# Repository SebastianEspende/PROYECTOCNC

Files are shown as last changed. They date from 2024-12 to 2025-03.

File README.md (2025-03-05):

# TALADRO CNC
### Introduccion

Este proyecto fue pensado y realizado con el fin de diseñar y construir un enrutador CNC de bajo costo, su 
principal función es agujerear placas PCB de producción caseras por estudiantes. Con este dispositivo se 
busca facilitar el proceso de la creación de proyectos que requieran placas electrónicas, permitiendo al 
usuario una mayor precisión y eficiencia en la perforación de placas, en comparación con los métodos 
manuales. Este proyecto también tiene como objetivo fomentar el aprendizaje practico de tecnologías CNC, 
de la electrónica y programación, con el fin de que sea una herramienta útil para los proyectos de electrónica 
y robótica.

#### Repositorio
- En el mismo se encuentran todos los recursos utilizados, como la parte electronica: donde se incluyen los diagramas y circuitos; los diseños 3D de las piezas utilizadas; y el codigo de programacion.
- No se incluyen las librerias, estas estaran al final de este archivo, algunas solo el nombre y otras en enlace a la pagina de donde provienen.

## Software

Se utiliza GRBL 1.1h, se incluye su link en el apartado de librerias

El codigo del ESP32 esta incluido por completo en este repositorio

## Para el futuro
A aquellos que les toque continuar nuestro proyecto, nos gustaria saberlo, les dejamos nuestros mails para que puedan contarnos, o si tienen alguna pregunta:
- espendesebastian@gmail.com
- josemcoronado671@gmail.com

### Palabras de precaución
los pines no son aleatorios, es importante que si quieren cambiarlo tengan en cuenta los grupos o puertos de los pines de un Arduino, si entran al cpu_map de GRBL se daran cuenta de lineas como esta para los 
pines que tienen algo en común como step de cada motor, dir de cada motor, limit switches, etc; 

```javascript
#define STEP_DDR        DDRD
#define STEP_PORT       PORTD
```
DDRD y PORTD no son solo nombres, se refieren al grupo de pines utiliado por los STEP en este caso, otro ejemplo
```javascript
#define DIRECTION_DDR     DDRD
#define DIRECTION_PORT    PORTD
```
Ambos utilizan el grupo D, que son del pin 0 al 7.
Grupo B utiliza pin 8 al 13.
es por eso que la declaracion de pines pareciera incorrecta, ejemplo 
#define X_LIMIT_BIT      1
Que utiliza el pin 9 pero se declara como 1, esto se debe a que utiliza el grupo B.

Para que la comunicacion entre el ESP32 y el Arduino funcione, tienen que tener el mismo GND, o al menos, conectarlos

### Librerias

- https://lcdmenu.forntoh.dev/overview/getting-started.html#installation
- https://github.com/gnea/grbl/releases/tag/v1.1h.20190825

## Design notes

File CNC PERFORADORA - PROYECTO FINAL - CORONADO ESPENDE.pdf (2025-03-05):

# PROYECTO FINAL

CICLO LECTIVO 2025

+

## CNC PERFORADORA DE PCB

# CORONADO JOSÉ | ESPENDE SEBASTIAN 7° ELECTRONICA E.S.E.T.P. N°703

## ÍNDICE

## CONTENIDO

## INTRODUCCIÓN

Este proyecto fue pensado y realizado con el fin de diseñar y construir un enrutador CNC de bajo costo, su principal función es agujerear placas PCB de producción caseras por estudiantes. Con este dispositivo se busca facilitar el proceso de la creación de proyectos que requieran placas electrónicas, permitiendo al usuario una mayor precisión y eficiencia en la perforación de placas, en comparación con los métodos manuales. Este proyecto también tiene como objetivo fomentar el aprendizaje practico de tecnologías CNC, de la electrónica y programación, con el fin de que sea una herramienta útil para los proyectos de electrónica y robótica.

Las placas PCB (Printed Circuit Board o circuito impreso) en nuestro ámbito estudiantil son muy importantes, ya que podemos definirlas como la culminación de un proyecto que hayamos realizado primeramente en una placa de pruebas o bien un diseño de un circuito que queramos armar. Las placas están conformadas por una o más capas, en el caso de los estudiantes acostumbramos a usar el tipo de placa que está conformado por un material aislante que puede ser una resina y una capa fina de cobre.

Cuando se realizan placas electrónicas de producción “caseras” se pueden emplear distintos métodos para la realización de pistas, que serán la conexión entre los componentes electrónicos, una de ellas es el uso de marcadores indelebles para realizar el trazo y recorrido de las pistas. Otro método es el uso de tóner, el cual primeramente debemos diseñar el circuito en algún programa como lo puede ser PCB Wizard o KiCad.

PCB WIZARD:

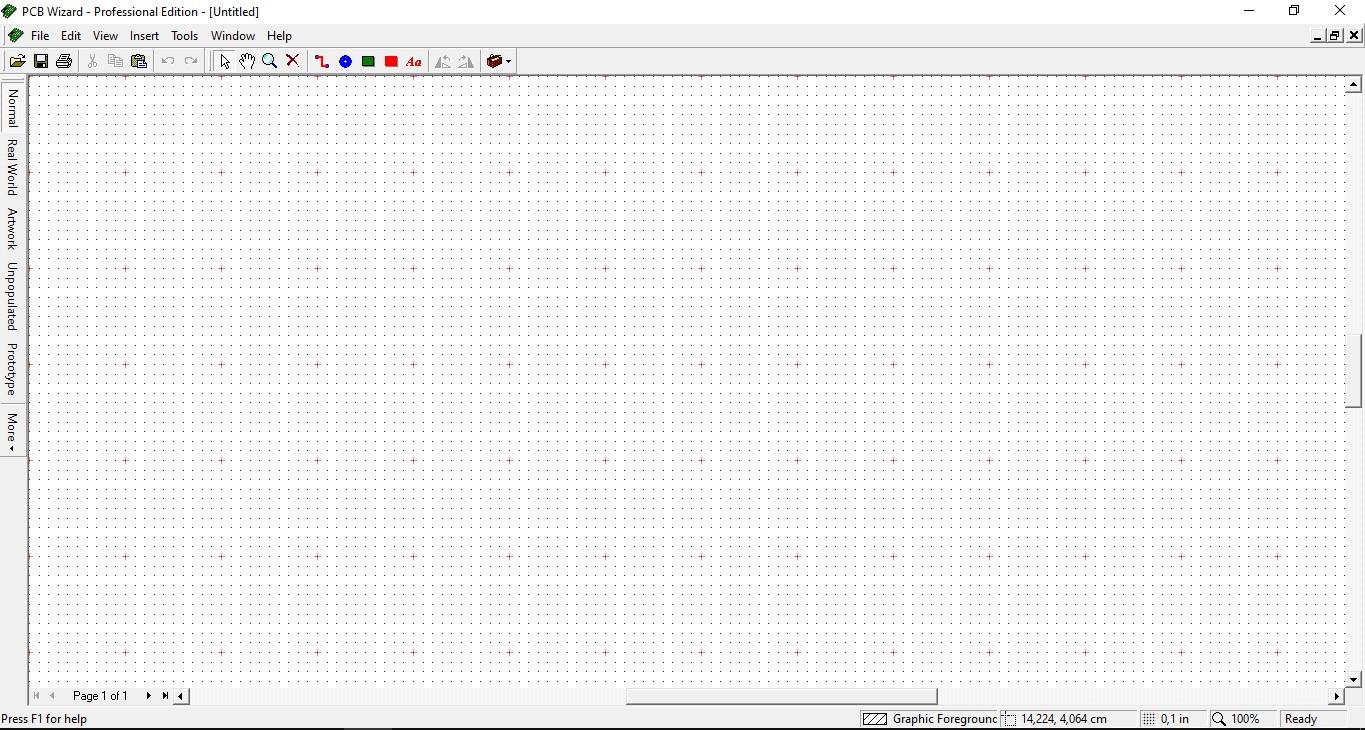
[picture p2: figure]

PCB Wizard es un software de diseño de circuitos impresos que destaca por su facilidad de uso y sus capacidades versátiles. Este programa tiene una interfaz sencilla y ofrece herramientas para diseñar un PCB estándar. Incluye funcionalidades como el dibujo esquemático, la conversión a circuito impreso y el posicionamiento de componentes electrónicos. Además, cuenta con una opción de autoruteado que simplifica el proceso de diseño.

Entre las características adicionales, PCB Wizard permite generar reportes de materiales, lo cual es crucial para llevar un control detallado de los componentes necesarios para el ensamblaje del circuito. También ofrece la posibilidad de realizar simulaciones para verificar el funcionamiento del diseño, con el programa Livewire, antes de la fabricación. La integración con otras herramientas de software y la capacidad de exportar archivos en distintos formatos hacen de PCB Wizard una opción atractiva tanto para estudiantes como para profesionales que buscan un software de diseño de PCBs eficiente y accesible.

KiCad:

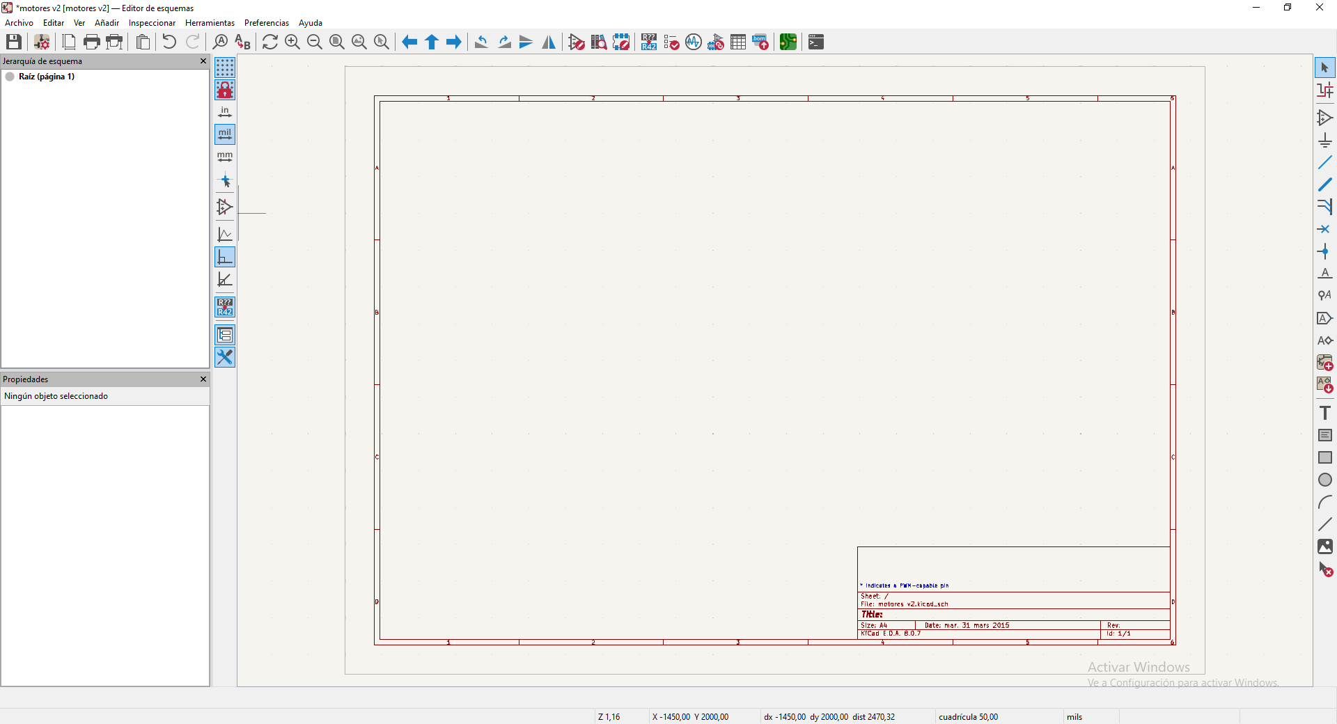
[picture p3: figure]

Este programa tiene una interfaz sencilla y ofrece herramientas avanzadas para el diseño de PCBs. Incluye dibujo esquemático, conversión a circuito impreso, posicionamiento de componentes, autoruteado y gestión de bibliotecas. Además, permite la visualización 3D del diseño y la generación de archivos Gerber para la fabricación de las placas. La integración con otras herramientas de software y la capacidad de exportar archivos en distintos formatos hacen de KiCad una opción atractiva tanto para estudiantes como para profesionales que buscan un software de diseño de PCBs eficiente y accesible.

Luego del proceso de fabricación de PCBs se requiere perforar la placa para poder realizar el montaje de los componentes electrónicos, tales como: componentes pasivos o componentes activos.

Para la realización de las perforaciones se puede usar taladros de mano o de banco, lo cual puede aumentar el error humano por las siguientes razones:

1. Precisión:
- Al perforar manualmente puede haber error en la alineación de la placa, debido a que no se utilizan guías o plantillas para mantener la estabilización de la placa. Esto puede representar un error de un 5% a 10% en la posición de los orificios.
2. Daños en la PCB:
- El error humano puede provocar daños en las pistas de cobre o en las islas de la placa, y este aumenta si se usa un taladro de mano, ya que se perfora en un ángulo incorrecto o se aplica demasiada fuerza. Esto puede representarse con un 3% a 5% de error en los agujeros.
3. Profundidad de perforación:
- La profundidad de los agujeros puede llegar a ser diferentes entre cada perforación, esto afecta al momento de colocar los componentes, ya que en algunos casos puede que estos no logren ingresar fácilmente por el orificio. Esto representa un 2% a 4% de error humano.
4. Tiempo y eficiencia:
- El tiempo requerido para perforar manualmente una PCB es mayor al que con una CNC, y el cansancio puede aumentar la probabilidad de errores.

El proyecto de la CNC busca reducir este margen de error humano, ya que el mismo posee un soporte/guía para mantener la placa estable, las perforaciones siempre se realizan a un ángulo recto de 90°, la fuerza aplicada es siempre la misma, la profundidad de igual manera siempre es la misma y el tiempo que emplea es mucho menor.

## MARCO TEORICO

Una CNC (Control Numérico Computarizado) es un dispositivo que se controla por computadora con el fin de cortar, tallar, grabar o perforar materiales con alta precisión. En el caso de este proyecto, el enrutador CNC está diseñado específicamente para la realización de perforaciones en placas PCB.

Una máquina CNC puede tener diferentes diseños y estar hecha de diversos materiales, pero hay componentes que son indispensables en todas ellas. Estos incluyen motores paso a paso, guías lineales y herramientas como perforadores o cortadores, dependiendo del uso que se les quiera dar.

Esta CNC está compuesta
por | varios | elementos
esenciales que trabajan en conjunto para garantizar su funcionamiento. Entre ellos, se encuentran los motores
paso a paso, que permiten
un movimiento preciso en
cada eje, las guías lineales,
que | facilitan | el
desplazamiento | suave | y
estable de la herramienta, y
el | motor | perforador,
encargado de realizar los
orificios en la placa PCB.

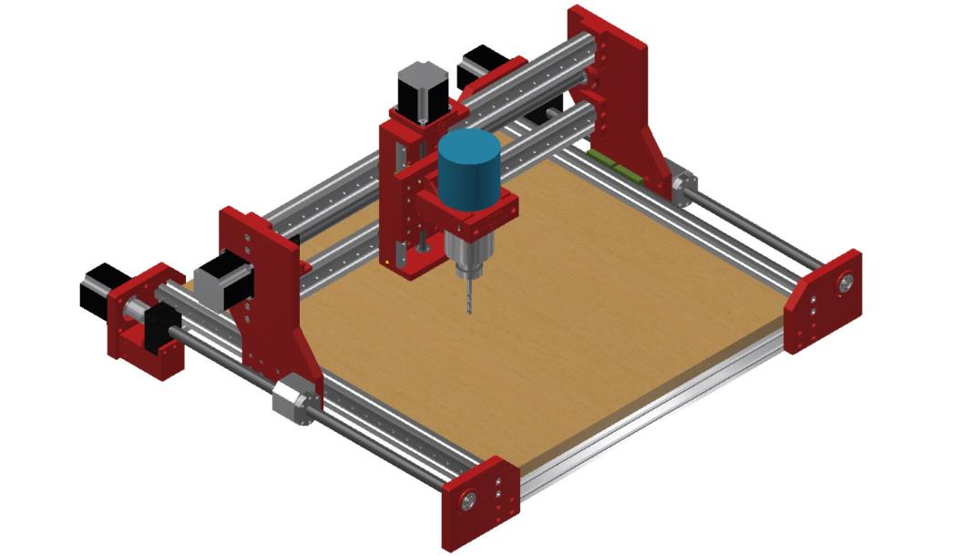
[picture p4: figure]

Además, la estructura y la placa de trabajo proporcionan la base necesaria para soportar todos estos componentes y asegurar la rigidez del sistema.

Los materiales utilizados en su fabricación pueden variar según el tipo de máquina y su propósito. En proyectos caseros o educativos, es común encontrar estructuras de aluminio, plásticos o madera, mientras que en la industria suelen emplearse materiales más robustos como el acero para garantizar mayor resistencia y durabilidad.

Cada uno de estos materiales y componentes cumple un rol fundamental en el rendimiento de la CNC. Una estructura firme reduce vibraciones y mejora la precisión, mientras que unas guías bien alineadas permiten movimientos más suaves. De esta manera, todos los elementos trabajan en conjunto para lograr perforaciones exactas y eficientes en las placas PCB.

## ESTRUCTURA

La estructura de una máquina CNC es una parte clave, ya que brinda soporte y estabilidad a todo el sistema. Está formada por un marco o chasis, guías lineales, husillos o tuercas, y una plataforma de trabajo. Todos estos elementos trabajan en conjunto para asegurar que la herramienta de perforación se desplace con precisión sobre la placa PCB.

## MOTORES PASO A PASO:

Los motores paso a paso son un componente esencial en una máquina CNC, ya que permiten un control preciso del movimiento en los ejes X, Y e Z. A diferencia de otros motores, los motores paso a paso se desplazan en incrementos exactos (pasos), lo que facilita un posicionamiento preciso de la herramienta de perforación sobre la placa PCB.

Estos motores funcionan mediante pulsos eléctricos que activan sus bobinas en una secuencia específica, generando movimientos controlados sin necesidad de sensores de posición adicionales. Existen dos tipos principales:

- Motores de pasos completos (full-step): Se mueven en pasos fijos, adecuados para aplicaciones donde la precisión no es extrema.
- Motores de micro pasos (microstepping): Dividen cada paso en fracciones más pequeñas, proporcionando mayor suavidad y precisión en los movimientos.

La elección del motor adecuado es muy importante en una CNC para PCB. Un motor con bajo torque podría perder pasos, causando errores en la perforación, mientras que un motor muy grande puede ser innecesario y consumir más energía. Generalmente, se utilizan motores NEMA 17 o NEMA 23, que ofrecen un buen equilibrio entre tamaño, potencia y precisión.

El uso de motores paso a paso en una CNC educativa permite a los estudiantes comprender principios de control de movimiento y automatización, habilidades fundamentales en la ingeniería y la manufactura.

## GUÍAS Y VARILLAS ENROSCADAS:

Las guías son un componente esencial en la estructura de la CNC, ya que permiten tanto la movilidad como la estabilidad del sistema. Las guías lineales, en particular, facilitan un movimiento lineal suave y preciso a lo largo de los ejes X, Y e Z. Estas guías están diseñadas para minimizar la fricción y el juego mecánico, lo que garantiza que los movimientos sean consistentes y exactos, incluso durante operaciones repetitivas. Esto es especialmente importante en aplicaciones como la perforación de placas PCB, donde la precisión en el posicionamiento es crítica para asegurar que los agujeros estén correctamente alineados y dimensionados.

Las varillas roscadas desempeñan un papel crucial en la conversión del movimiento rotativo del eje del motor en movimiento lineal. Cuando el motor paso a paso gira, la rotación se transmite a la varilla roscada, que a su vez mueve una tuerca o un acoplador a lo largo de su longitud. Este mecanismo permite un desplazamiento lineal preciso y controlado, esencial para el posicionamiento exacto de la herramienta de corte en los ejes X, Y y Z de la CNC. La precisión de este sistema depende en gran medida del paso de la rosca de la varilla, que determina la distancia que se desplaza la tuerca por cada vuelta completa del motor. Este diseño es fundamental para garantizar movimientos suaves y repetibles, lo que es especialmente importante en
aplicaciones | como | la | perforación | de | placas | PCB, | donde | la | exactitud | es | crítica.

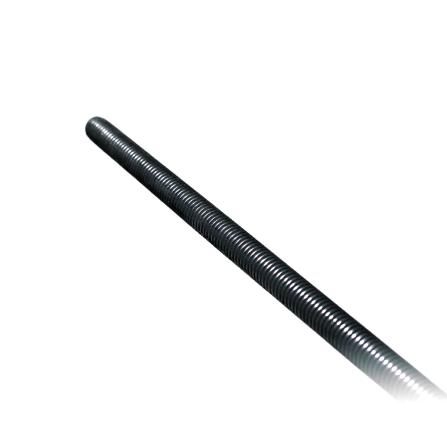
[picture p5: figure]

## SISTEMA DE CONTROL

El sistema de control es el "cerebro" de la máquina CNC, ya que se encarga de interpretar las órdenes y convertirlas en movimientos precisos en los ejes de la máquina. En este caso, el sistema está basado en una placa programable Arduino junto con el firmware de código abierto GRBL, una combinación que permite analizar y ejecutar instrucciones escritas en código G.

El código G es el lenguaje estándar utilizado en máquinas CNC para indicar qué movimientos debe realizar la herramienta de trabajo. Cuando se carga un archivo con código G en la CNC, el Arduino con GRBL lo interpreta y envía las señales necesarias a los controladores de los motores paso a paso, quienes a su vez mueven la herramienta en los ejes X, Y e Z con precisión.

Uno de los principales beneficios de este sistema es su bajo costo en comparación con controladores CNC comerciales, que pueden ser bastante costosos. Además, al ser un sistema de código abierto, GRBL es accesible y ampliamente utilizado, lo que significa que cuenta con una gran comunidad de usuarios y desarrolladores que ofrecen soporte, mejoras y soluciones a posibles problemas.

Otra ventaja es su facilidad de uso y configuración. No se necesita un software complejo para programarlo, y se puede controlar desde una computadora mediante programas como Universal Gcode Sender o Candle, que permiten cargar y enviar los archivos de código G de manera sencilla.

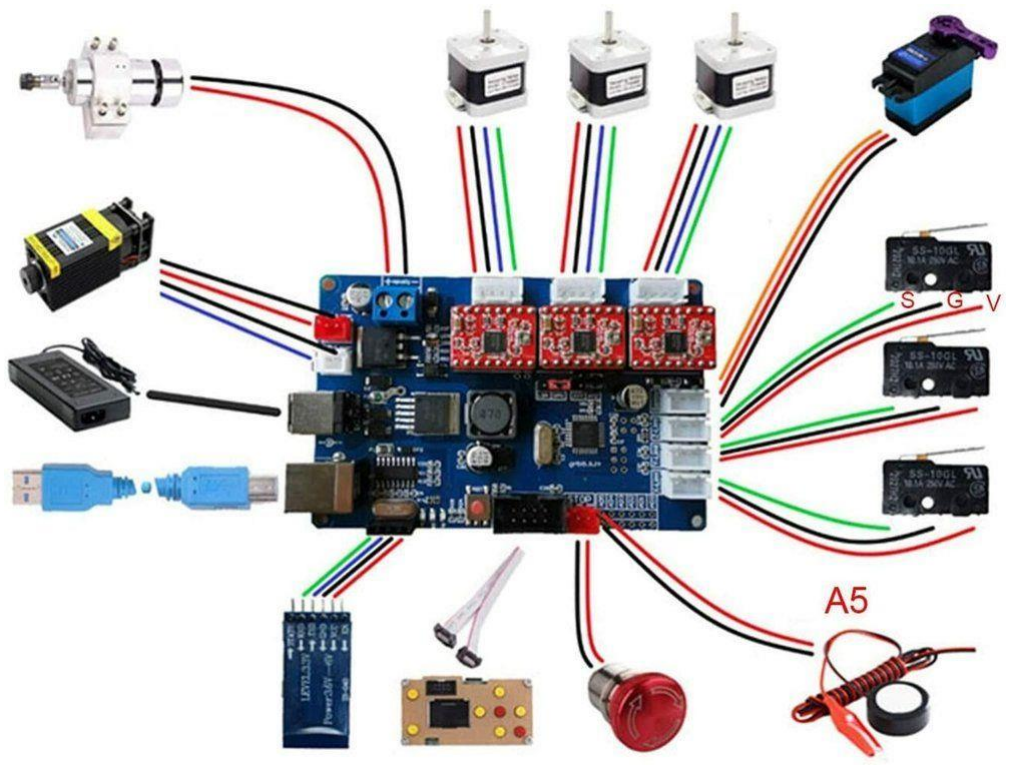
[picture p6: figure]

En esta imagen podemos apreciar los materiales básicos para una CNC, en donde tenemos los 3 motores paso a paso, 3 fines de carreras para limitar la posición de los ejes, un elemento perforador o cortador, una fuente de poder, un lector de memorias SD, una pantalla con pulsadores, los drivers de motores, etc.…

## DISEÑO Y DESARROLLO

## ETAPAS DEL DISEÑO CNC:

El primer paso en el desarrollo de la CNC fue la creación de un prototipo digital utilizando SolidWorks, un software especializado en diseño 3D. Este programa permitió modelar cada uno de los componentes de la máquina, como la estructura, los motores, las guías lineales y el sistema de perforación, asegurando que todas las piezas encajaran correctamente antes de la fabricación.

Gracias a SolidWorks, fue posible visualizar el diseño en un entorno virtual, realizar simulaciones de movimiento y detectar posibles fallos estructurales o de ensamblaje. Además, nos permitió optimizar el uso de materiales y prever los ajustes necesarios para garantizar un montaje preciso y funcional.

Una vez que el diseño digital estuvo finalizado y validado, se procedió a la fabricación del prototipo físico, utilizando los materiales adecuados y ensamblando cada componente según lo planificado en el modelo 3D. Este proceso facilitó la transición del diseño teórico a una máquina real, minimizando errores y asegurando un mejor resultado en la construcción de la CNC.

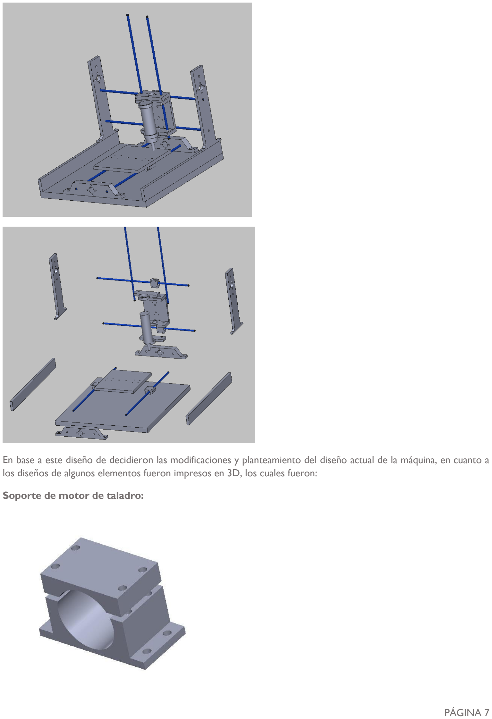
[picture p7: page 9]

En base a este diseño de decidieron las modificaciones y planteamiento del diseño actual de la máquina, en cuanto a los diseños de algunos elementos fueron impresos en 3D, los cuales fueron:

Soporte de motor de taladro:

Soporte eje Y:

El mismo consta con dos orificios para la colocación de rodamientos lineales que permitirán un movimiento más suave por los ejes.

Soporte lineales:

Estos soportes son utilizados en conjunto con un rodamiento lineal, se utilizan en los ejes X e Z.

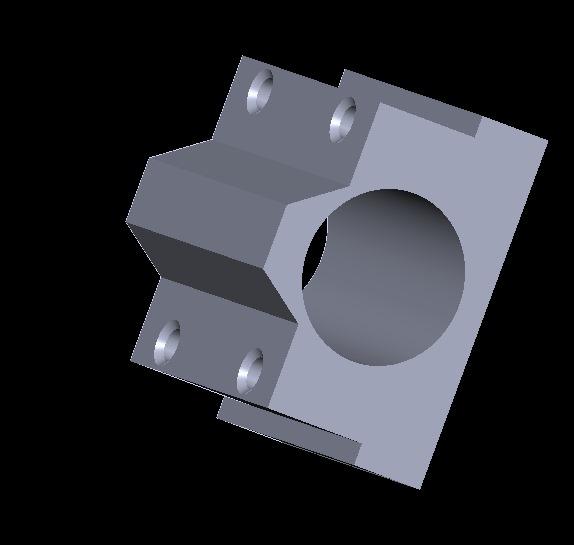
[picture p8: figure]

Soporte para motores Nema17:

Se utiliza para soportar los motores, los orificios chicos son para el acople del motor y los separadores son para acoplar a la base del CNC.

Soporte de tuerca M8:

El soporte en conjunto con una tuerca, se encargan del desplazamiento en los ejes.

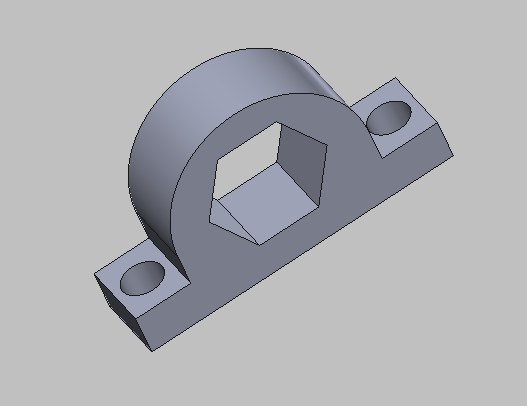
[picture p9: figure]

Soporte del eje X:

Este soporte acoplado a la base soporta dos varillas lineales y el motor en el centro.

Base:

Una tabla de madera con una medida de 400mm x 400mm

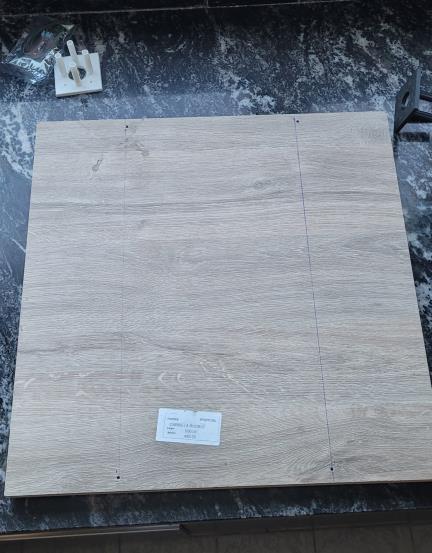
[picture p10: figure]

Se deben realizar cuatro perforaciones en las piezas con medidas precisas, ya que estas deben acoplar los soportes de las guías y varillas del eje X.

Soportes laterales:

Dos maderas de 100mm x 400mm

A cada una de las maderas se le deben realizar tres perforaciones. Dos de ellas con un diámetro de 8 mm que están destinadas a acoplar las varillas guías que conectan las piezas. La perforación central, por su parte, tiene un diámetro de 22 mm. En una de las maderas, se debe instalar un rodamiento con medidas de 8 mm en su diámetro interior y 22 mm en el exterior.

Estas maderas cumplen la función de soportes laterales de la estructura. Junto con las varillas guías, permiten el desplazamiento suave y preciso del taladro a lo largo del eje Z de la CNC, facilitando el movimiento vertical necesario para
realizar | las | perforaciones | en | las | placas | PCB.

## PROCESO DE ARMADO:

En esta etapa además de los materiales previamente mencionados, se necesitan de materiales menores, tales como: tornillos; tuercas; arandelas; varillas roscadas; etc.

Estos se pueden conseguir fácilmente en ferreterías.

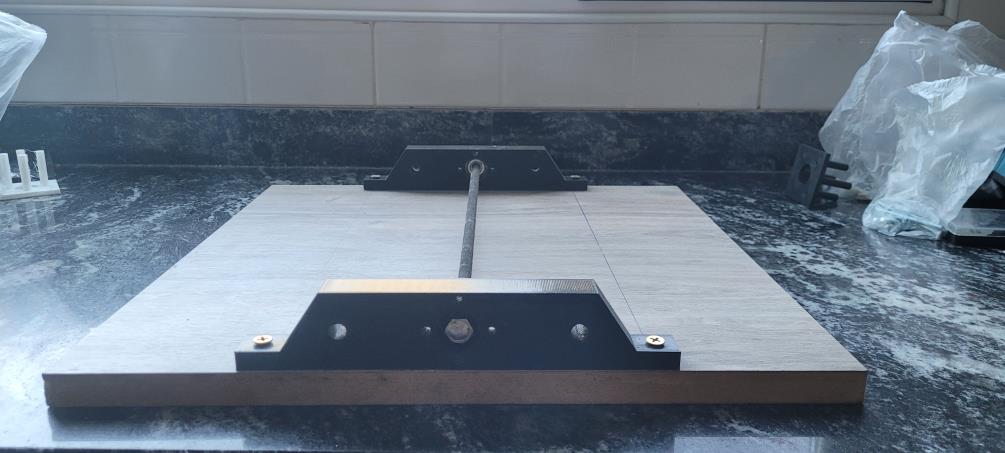
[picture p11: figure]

Se debe acoplar los soportes del eje X a la tabla de 400mm x 400mm, se debe comprobar
que ambas estén en las mismas posiciones para que a futuro no haya problemas de alineación para que los motores no tengan que esforzarse demás por la fricción.

Se debe colocar los soportes lineales a la base y colocar en el centro una tuerca M8 para que se realice el movimiento lineal según el giro del motor. La sujeción de los soportes y la tuerca se puede realizar con tornillos u pegamentos.

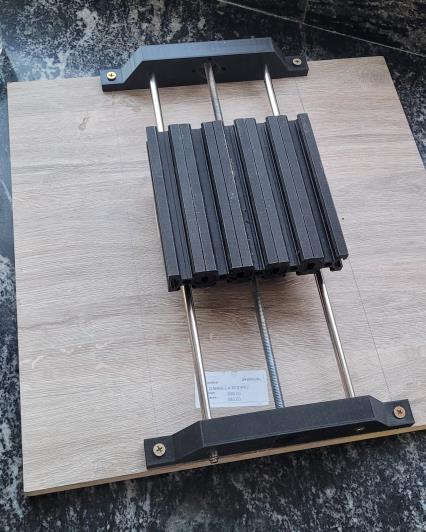
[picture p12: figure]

Una vez armada la base con sus soportes, se deben colocar las varillas y comprobar que la base se desplace según el giro de la varilla.

Terminando esta etapa del proyecto se puede realizar el montaje de los otros ejes, debido a que se necesita saber la posición de la base cuando se encuentra en uno de los extremos.

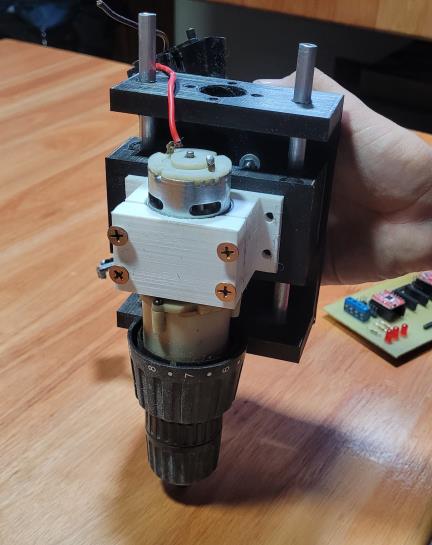
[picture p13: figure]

Previamente se debe realizar el montaje del taladro, el mismo consta de 3 piezas impresas 3D, en donde uno es el soporte del motor, otro es el soporte que realizara el movimiento vertical y por último el soporte que realizara el movimiento horizontal.

Para el taladro se reciclo el motor y el mandril de un taladro de mano.

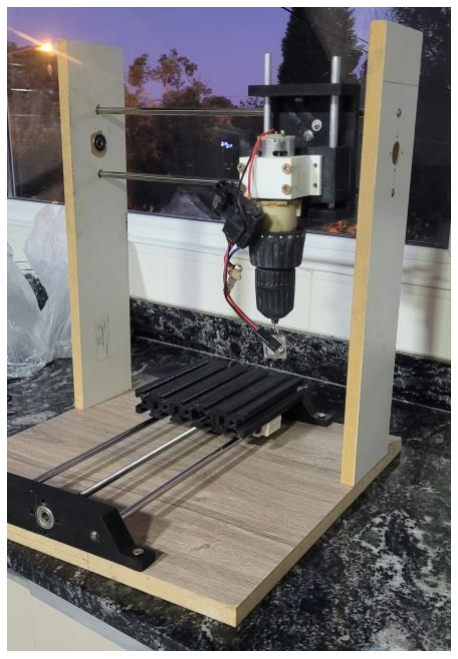
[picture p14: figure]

Teniendo todas las piezas armadas y en posición, se puede realizar el montaje de todas las maderas a la base, hay que comprobar las posiciones antes de
realizar | las | perforaciones.

## PARTE ELECTRONICA:

Para la parte electrónica del proyecto se requieren de varios materiales, que bien fácilmente se pueden comprar o armar por nosotros mismos:

- Shield Arduino:

Este shield de Arduino Uno es una opción buena para este proyecto, pero en el caso de este proyecto se fabricó un prototipo de este shield.

Circuito esquemático:

Este shield cuenta con las conexiones para los motores paso a paso, la salida de 12V para el motor del taladro, los fines de carrera y una conexión RX e TX para conectar el Arduino con el ESP32.

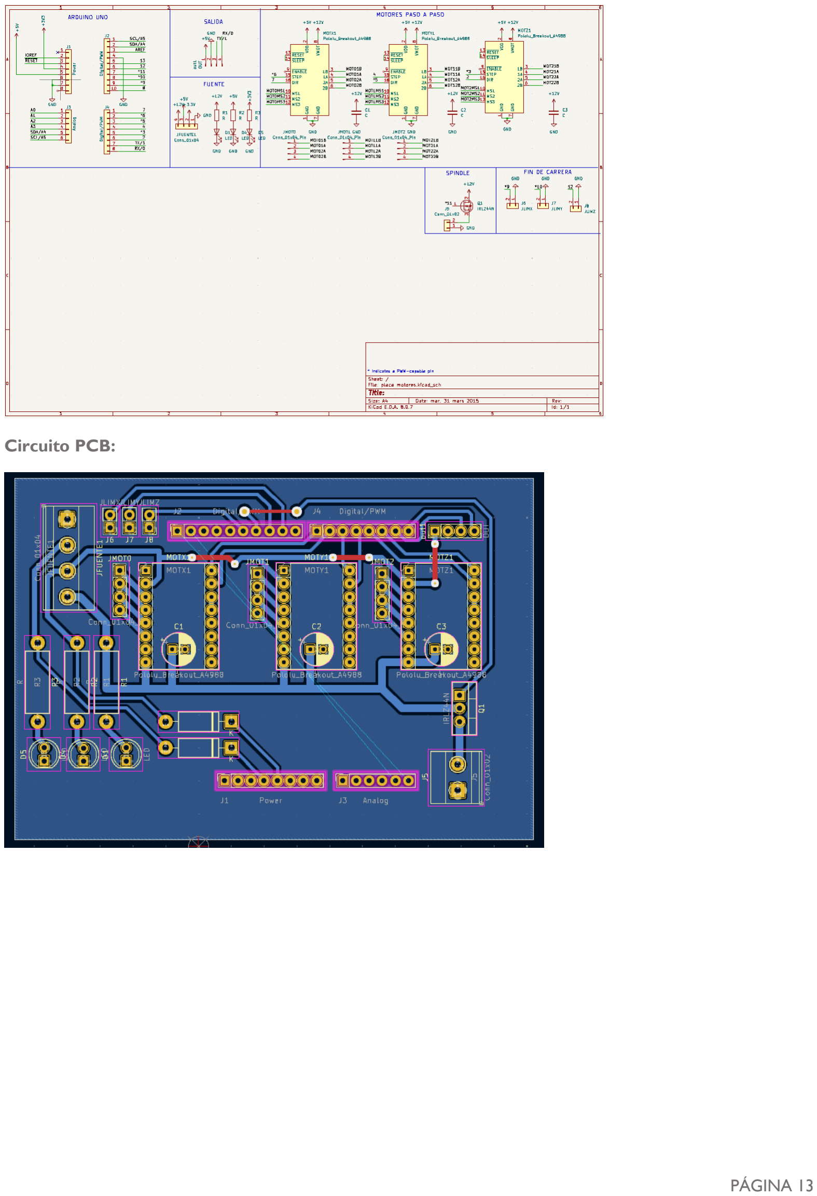
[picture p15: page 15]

Circuito PCB:

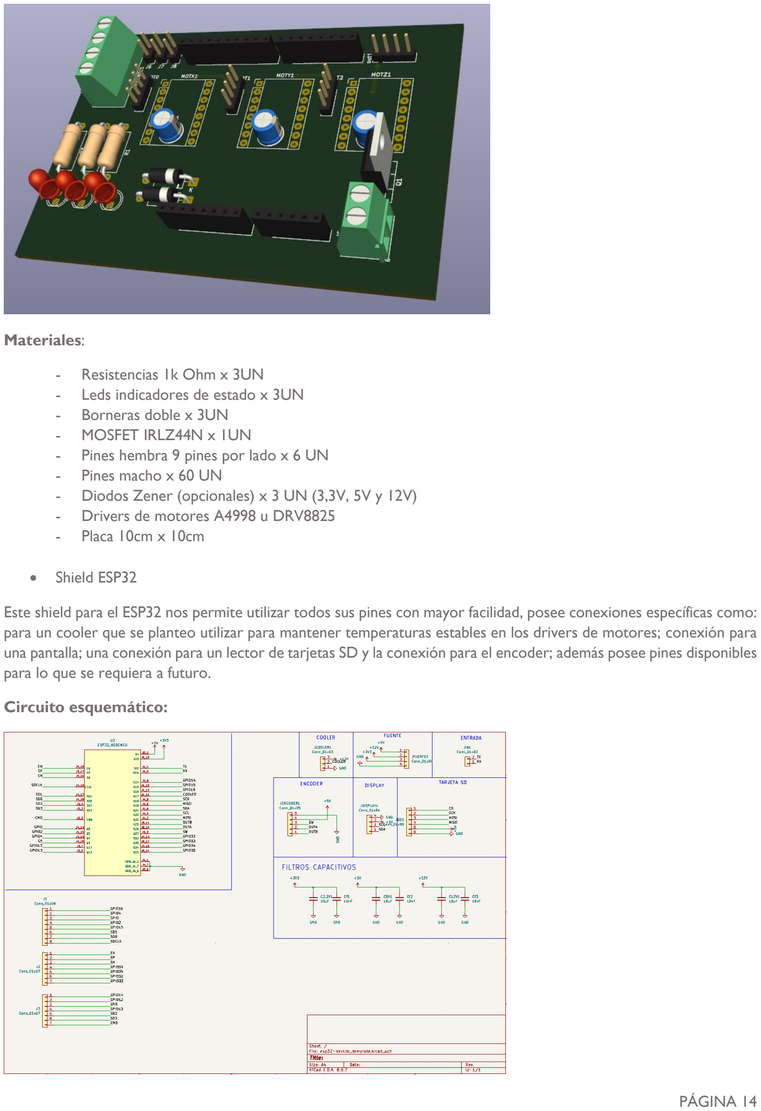
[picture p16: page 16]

Materiales:

- Resistencias 1k Ohm x 3UN
- Leds indicadores de estado x 3UN
- Borneras doble x 3UN
- MOSFET IRLZ44N x 1UN
- Pines hembra 9 pines por lado x 6 UN
- Pines macho x 60 UN
- Diodos Zener (opcionales) x 3 UN (3,3V, 5V y 12V)
- Drivers de motores A4998 u DRV8825
- Placa 10cm x 10cm
- Shield ESP32

Este shield para el ESP32 nos permite utilizar todos sus pines con mayor facilidad, posee conexiones específicas como: para un cooler que se planteo utilizar para mantener temperaturas estables en los drivers de motores; conexión para una pantalla; una conexión para un lector de tarjetas SD y la conexión para el encoder; además posee pines disponibles para lo que se requiera a futuro.

Circuito esquemático:

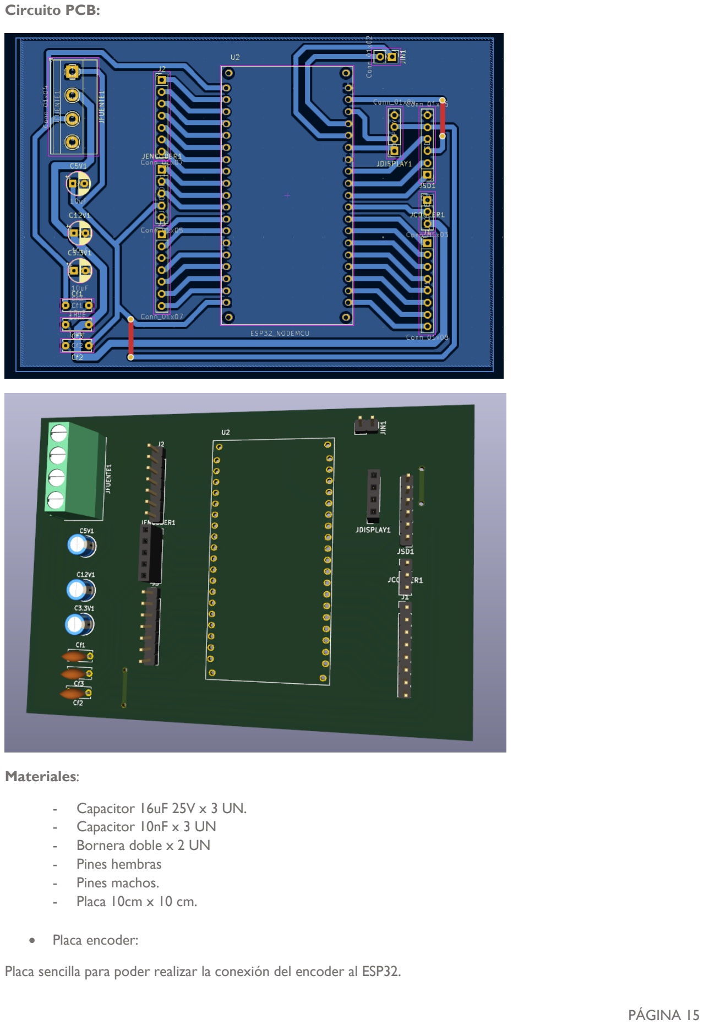
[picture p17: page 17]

Circuito PCB:

Materiales:

- Capacitor 16uF 25V x 3 UN.
- Capacitor 10nF x 3 UN
- Bornera doble x 2 UN
- Pines hembras
- Pines machos.
- Placa 10cm x 10 cm.
- Placa encoder:

Placa sencilla para poder realizar la conexión del encoder al ESP32.

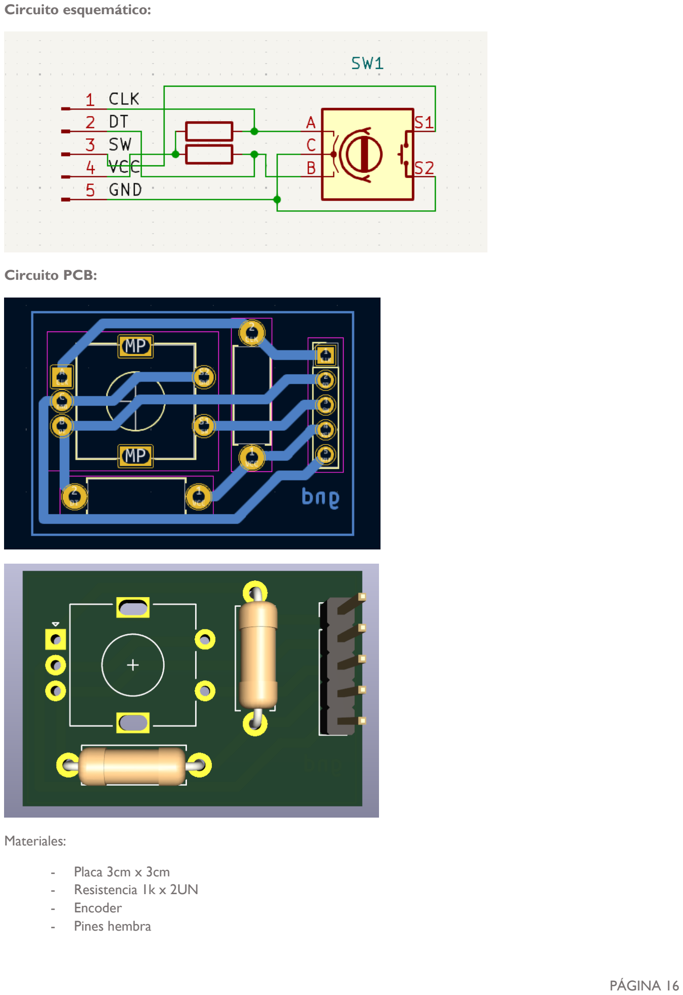
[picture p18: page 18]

Circuito esquemático:

Circuito PCB:

Materiales:

- Placa 3cm x 3cm
- Resistencia 1k x 2UN
- Encoder
- Pines hembra

- Alimentación:

Para la alimentar toda la maquina se puede utilizar una fuente de poder reciclada, en donde necesitaremos realizar unas modificaciones debido a que únicamente necesitaremos 4-5 cables de esta.

## GRBL

GRBL es un firmware de código abierto y alto rendimiento para controlar máquinas CNC (Control Numérico
Computarizado), | como | fresadoras, | grabadoras | láser | y | cortadoras | de | plasma.

GRBL recibe comandos en G-code, un lenguaje de programación estándar utilizado en la industria CNC. El G-code especifica las coordenadas, velocidades y otras instrucciones para el movimiento de la herramienta. GRBL actúa como un intérprete, traduciendo estos comandos en señales eléctricas que controlan los motores de la máquina.

Este está diseñado para controlar motores paso a paso, que son motores eléctricos que giran en incrementos precisos. El firmware genera pulsos eléctricos que controlan el movimiento de los motores, permitiendo un posicionamiento preciso de la herramienta. GRBL optimiza la aceleración y desaceleración de los motores para lograr movimientos suaves y precisos.

## SOFTWARE ESP-32

## COMUNICACION CON GRBL

Los creadores de GRBL, recomiendan varios protocolos de comunicación para interconectar con GRBL, en nuestro
caso | utilizaremos | un | protocolo | de | transmisión | envio-respuesta

El protocolo de transmisión de envío-respuesta se presenta como el método más robusto y sencillo para la transmisión de programas de código G a GRBL. Este protocolo opera mediante el envío secuencial de líneas de código G desde el transmisor a GRBL, seguido de una espera de confirmación, ya sea una respuesta 'ok' o 'error', antes de proceder con el envío de la siguiente línea.

Esta metodología garantiza la integridad de la transmisión al sincronizar la ejecución entre el transmisor y GRBL. La confirmación de recepción permite que el transmisor verifique que cada línea de código G ha sido procesada correctamente por GRBL, independientemente de las posibles demoras en el procesamiento o la ejecución de las instrucciones por parte de GRBL.

La implementación de este protocolo asegura que no se pierdan instrucciones y que la secuencia de ejecución se mantenga precisa, lo que resulta crucial para la operación correcta de sistemas de control numérico.

Comenzamos | definiendo | dos | protocolos | UART | en | el | ESP32

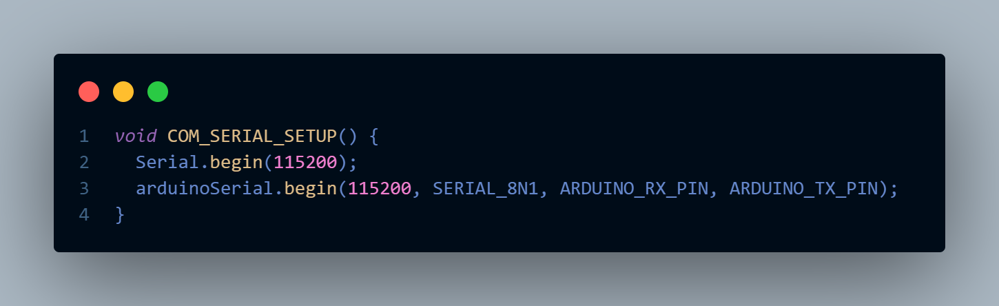
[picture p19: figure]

Serial se utilizará para monitorear el comportamiento del ESP32 y para debuggear cualquier error.

Arduino Serial se utilizará para comunicarse del GRBL

Esta distinción se debe a que, si queremos utilizar la misma interfaz UART toda información enviada del esp32 será recibida por el Arduino, incluido cualquier mensaje de debug, lo que puede traer conflicto con GRBL.

Luego de esto, continuamente revisaremos si hay algún mensaje que ha sido enviado por GRBL:

En un archivo de código G, cada línea es uno o varios movimientos de distintos tipos, desde precisos hasta lineales rápidos. Necesitamos enviar línea por la línea del archivo al GRBL, por lo que, necesitamos una función que procesé un archivo seleccionado y envié la información a GRBL

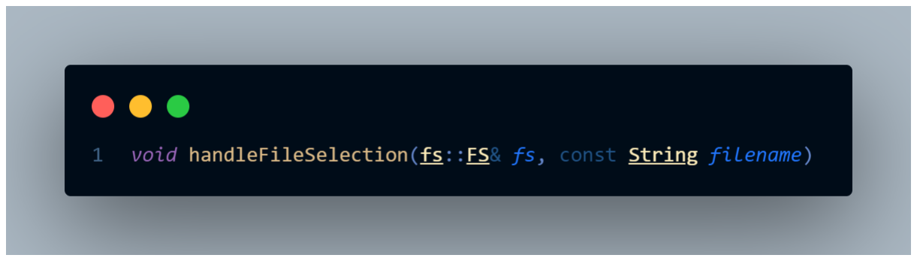
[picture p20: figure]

HandleFileSelection hace exactamente eso, empieza intentando abrir el archivo y devolver un error en caso de que sea necesario:

Una vez que pasemos este proceso, sabemos que el archivo se ha podido abrir correctamente por lo que prosigue
procesar | las | líneas:

GRBL distingue una línea de otra ya sea por una nueva línea “\n” o un “retorno de carruaje” “\r”

Nótese la distinción entre enviar la línea al Serial y al Serial de comunicación con GRBL

Además, no queremos enviar una línea vacía, por lo que debemos asegurarnos de que ese no sea el caso.

Mas adelante se explicará cómo se selecciona el archivo.

## TARJETA SD

Hay tres cosas importantes que se deben hacer con la tarjeta SD, poder listar todos los archivos que contiene, accederlos y leer cada línea.

Para | la | primera | listDir | hace | exactamente | eso.

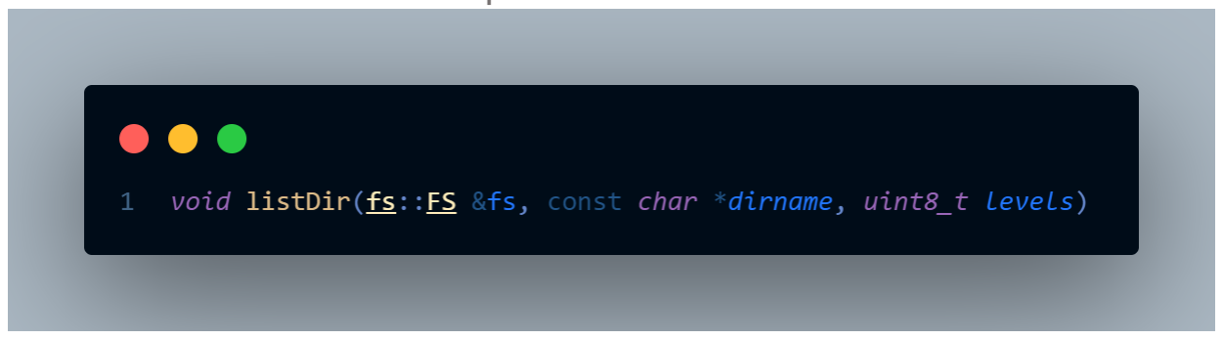
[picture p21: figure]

Su funcionamiento es muy sencillo, simplemente utilizaremos la librería incluida con el ESP para acceder a la ruta y a
cada | uno | de | sus | archivos

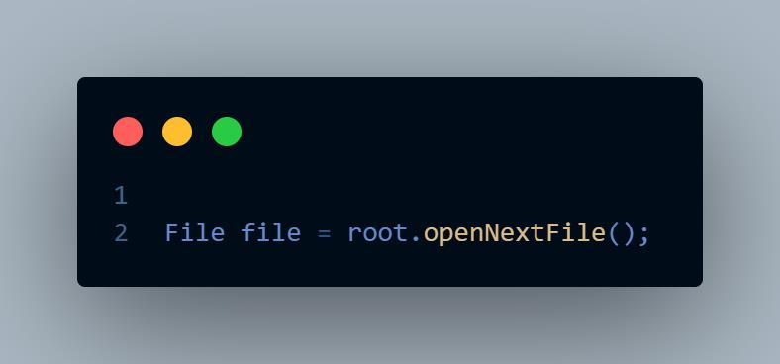
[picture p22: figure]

También | debemos | asegurarnos | de | incluir | cualquier | carpeta | dentro | del | directorio:

Leer cada línea es aún más simple, una vez comenzamos a leer el archivo simplemente nos detendremos en cada “\n”
o | “\r”

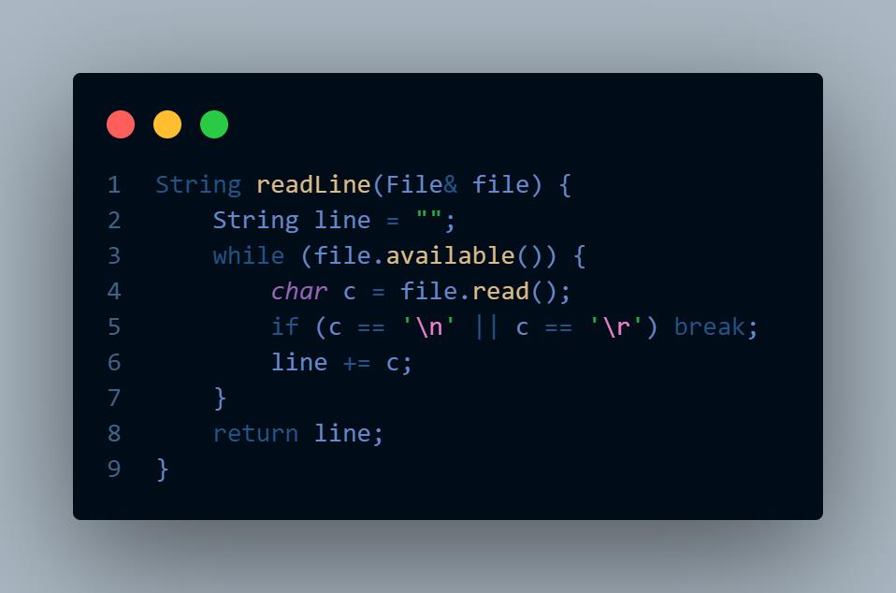
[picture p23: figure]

## WIFI

El WIFI se utilizará para conectarse al servidor y poder recibir archivos a través de la red y no tener que utilizar la
tarjeta | | | | | | | | | | | | SD.
Actualmente | solo | podemos | conectarnos | a | internet, | pero | no | podemos | hacer | nada | con | eso.

Comenzamos poniendo la antena en modo estación, en la que solo podemos enviar y recibir, luego conectándonos a una red a través de wifistart, que enviara los valores por defecto de SSID y contraseña, que en caso de que no sea
modificado | | | estarán | | | | vacíos.
BuildWifiScreen | será | explicado | en | el | apartado | de | LCD.
Debemos hacer dos cosas en este apartado, escanear las redes y conectarnos.

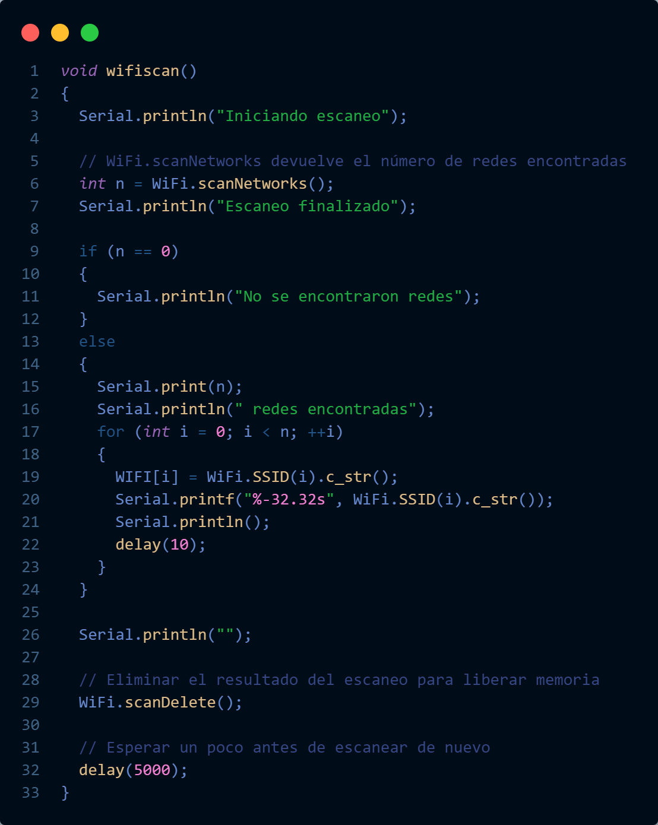
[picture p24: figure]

Wifiscan, hace exactamente lo que dice su nombre, buscamos las redes disponibles y las guardamos en un Array para su uso posterior.

Wifistart nos conectara dado un SSID y una contraseña, y logeara su resultado.

## LCD

El | LCD | es | lo | que | nos | permite | controlar | la | CNC, | por | tanto, | debemos | poder:
- | Seleccionar | un | archivo | ya | sea | desde | la | SD | o | el | Servidor.
- | Conectarnos | a | WIFI
- Obtener información sobre el estado actual de la maquina

Archivos

Con lo explicado antes en el apartado de SD, ya tenemos una manera de enlistar todos los archivos dentro de un directorio, por lo que simplemente deberemos crear un nuevo ítem para cada archivo, con una función como callback para poder hacer algo sobre él.

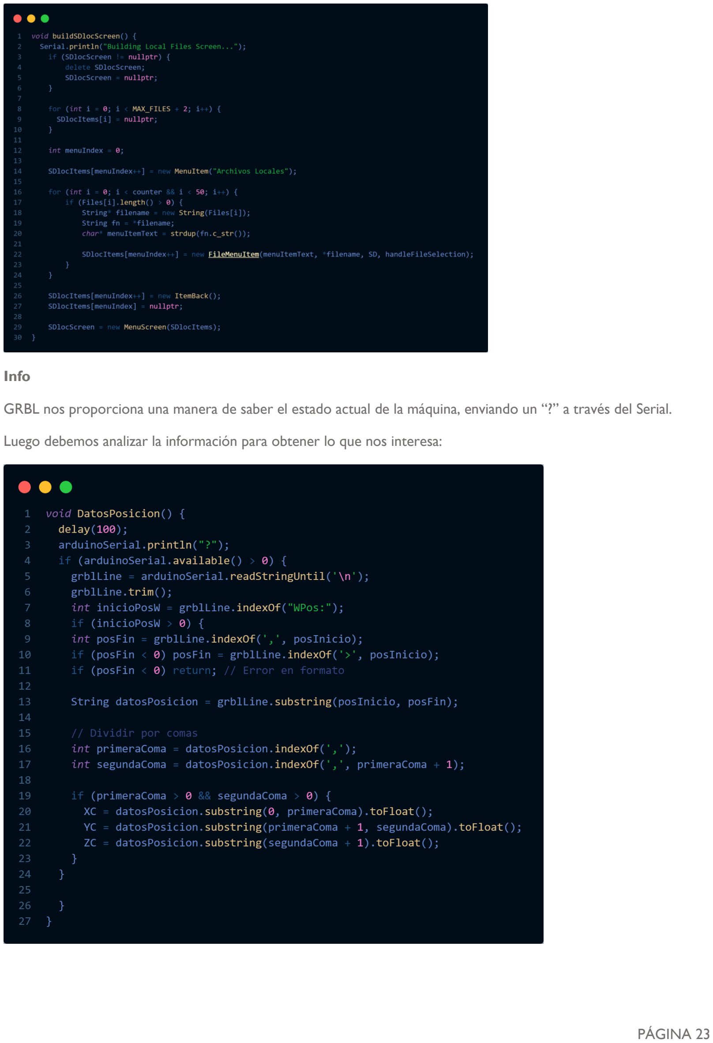
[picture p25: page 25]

Info

GRBL nos proporciona una manera de saber el estado actual de la máquina, enviando un “?” a través del Serial.

Luego debemos analizar la información para obtener lo que nos interesa:

## CONCLUSIÓN

Este proyecto fue interesante de abordar. Al principio nos confiamos con los tiempos y pensamos que iba a ser algo rápido de armar, pero fue todo lo contrario, con las cursadas de las materias, las pasantías y temas de universidad no pudimos entregarlo en tiempo y forma.

Luego al diseñar lo que seria la estructura nos vimos con varias dificultades, como: “¿Cómo hacemos la base?”, “¿Y si probamos agregando esto?” “¿Se le puede poner esto?” Y así con muchas preguntas, fuimos resolviendo poco a poco y conseguimos el diseño final.

Un verdadero problema fue el diseño del shield del Arduino, no solo el diseño, sino que también el desarrollo, teniéndolo que rehacer como 4-5 veces, es por esto por lo que es importante repasar varias veces los circuitos antes de pasarlos a una placa. Ya que no es solo una perdida de dinero, sino que también de tiempo, nosotros precisábamos la placa antes de las vacaciones, por lo que la hicimos de manera apurada durante el ciclo lectivo, pero al momento de empezar a armar el proyecto nos dimos cuenta que estaba mal, y decíamos “¿Y ahora que hacemos”, debido a que la escuela estaba cerrada y no teníamos como conseguir los materiales de forma local, así que tuvimos que comprar desde Buenos Aires, y con las demoras que hubieron, pasaron los días lo cual fue tiempo perdido, ya que sin la placa no podíamos hacer mucho más. En cuanto llegaron los materiales, lo armamos lo más rápido que pudimos y empezamos a probar los motores.

A pesar de las complicaciones que tuvimos, pudimos resolverlas y concretamos el proyecto.

## BIBLIOGRAFIA

Qué Es Una Máquina CNC Y Su Funcionamiento Explicado✅ (https://cea-delsur.com/que-es-una-maquina-cnc-y-su-funcionamiento-explicado/)

CÓMO CONSTRUÍ MI CNC PARTE1 - Electrónica Práctica Aplicada (https://www.diarioelectronicohoy.com/blog/como-construi-mi-cnc-parte1)

GRBL with Arduino CNC Shield – Complete Guide (https://www.youtube.com/watch?v=Xlkmso01vUk&t=1101s)

ESP32 UART Communication Pins Explained with Example (https://microcontrollerslab.com/esp32-uart-communication-pins-example/)

ESP32 UART - Serial Communication, Send and Receive Data (Arduino IDE) | Random Nerd Tutorials (https://randomnerdtutorials.com/esp32-uart-communication-serial-arduino/)

Connect ESP32 to WiFi - Step-By-Step Tutorial (https://www.youtube.com/watch?v=aAG0bp0Q-y4)

ESP32: Guide for MicroSD Card Module Arduino | Random Nerd Tutorials (https://randomnerdtutorials.com/esp32-microsd-card-arduino/)

GitHub - grbl/grbl: An open source, embedded, high performance g-code-parser and CNC milling controller written in optimized C that will run on a straight Arduino (https://github.com/grbl/grbl)

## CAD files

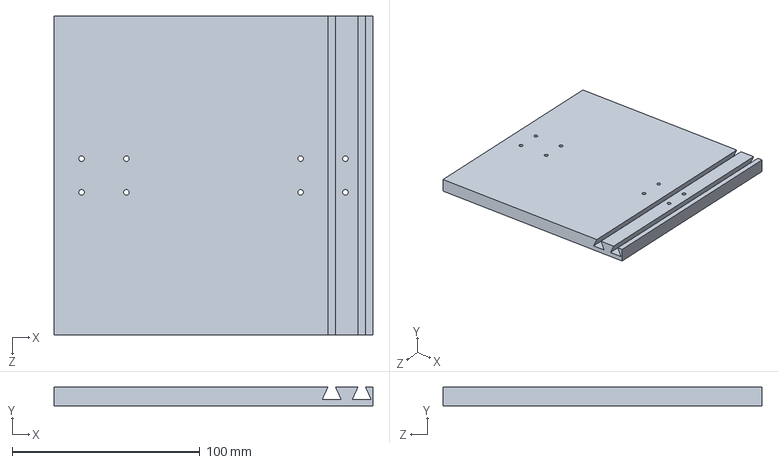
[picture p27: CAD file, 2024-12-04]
3d/Assem3.SLDASM
170.0 x 10.0 x 170.0 mm

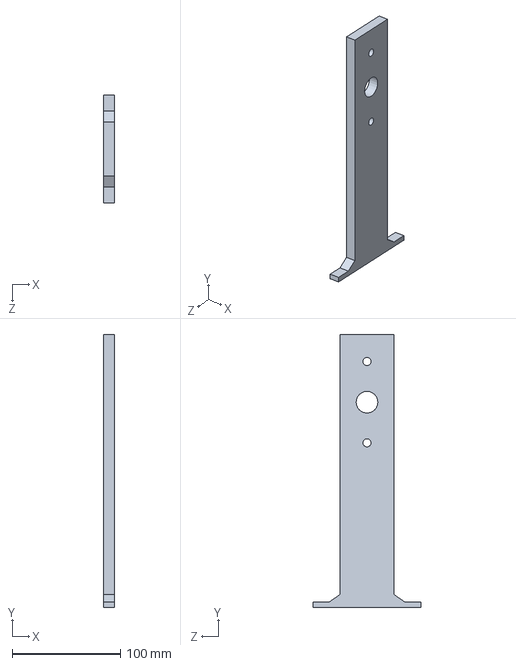
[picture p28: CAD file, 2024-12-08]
3d/LADOS.SLDPRT
10.0 x 252.0 x 100.0 mm

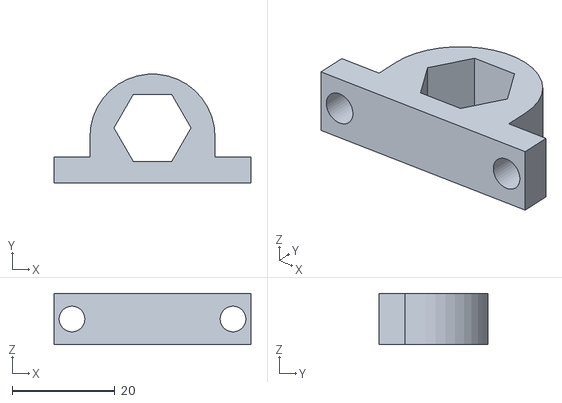
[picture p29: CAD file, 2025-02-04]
3d/stl/varilla_enroscada_tuerca.stl
38.4 x 21.1 x 10.0

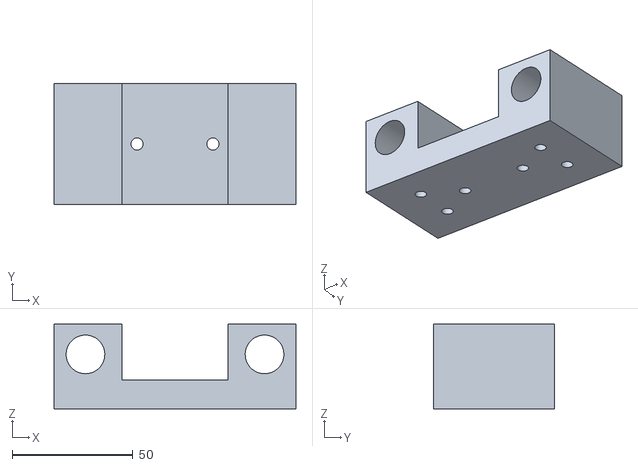
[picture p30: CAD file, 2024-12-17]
3d/stl/agarreZ.STL
100.0 x 50.0 x 35.0

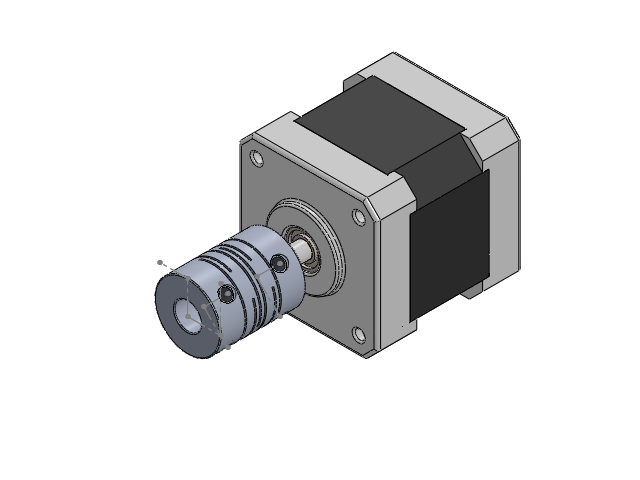
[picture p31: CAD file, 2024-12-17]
3d/v2/NEMA 17.SLDASM
Cuerpo
Tapa
pan cross head_am x 4
Eje
instrument ball bearing_68_am x 2
NEMA17_Coupler

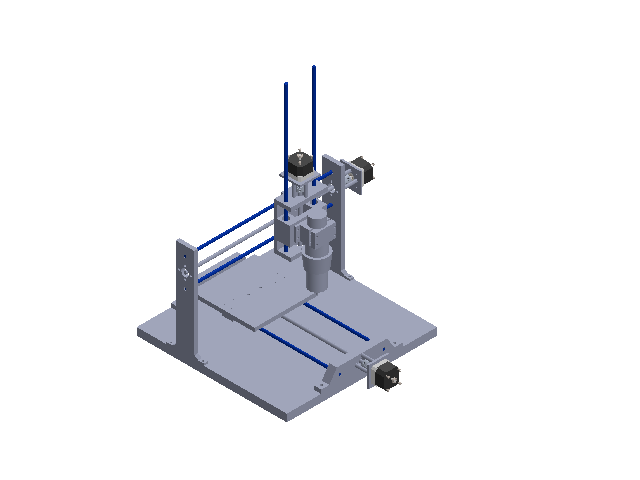
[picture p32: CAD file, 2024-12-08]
3d/v2/Assem2.SLDASM
BASE
FRONTAL_BASE x 2
GUIA_RAIL_VARILLA x 6
GUIA_LINEAL x 4
BASE_PLACA
LADOS x 2
Y
Motor2
agarremotor
agarreZ
varilla_enroscada_tuerca x 3
soportenema17 x 3
Cuerpo x 3
Tapa x 3
pan cross head_am x 12
Eje x 3
instrument ball bearing_68_am x 6
NEMA17_Coupler x 3
varilla_enroscada x 2
varilla_enroscada_Z

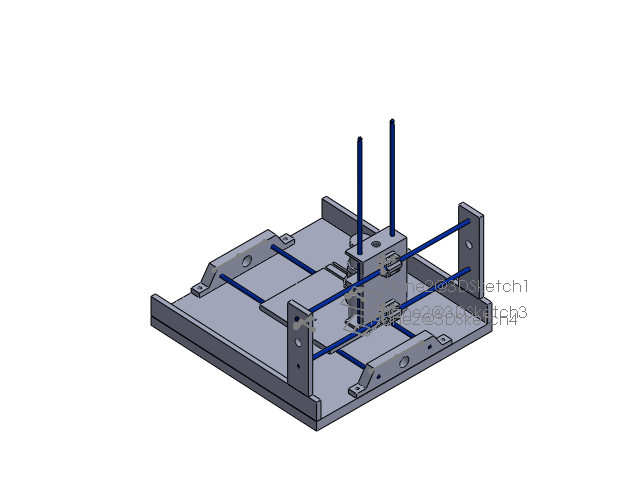
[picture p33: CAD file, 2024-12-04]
3d/Fin.SLDASM
BASE
FRONTAL_BASE x 2
GUIA_RAIL_VARILLA x 6
GUIA_LINEAL x 4
BASE_PLACA
Part1^Fin
Part2^Fin
LADOS x 2
Y
Agarre_motor
Motor2

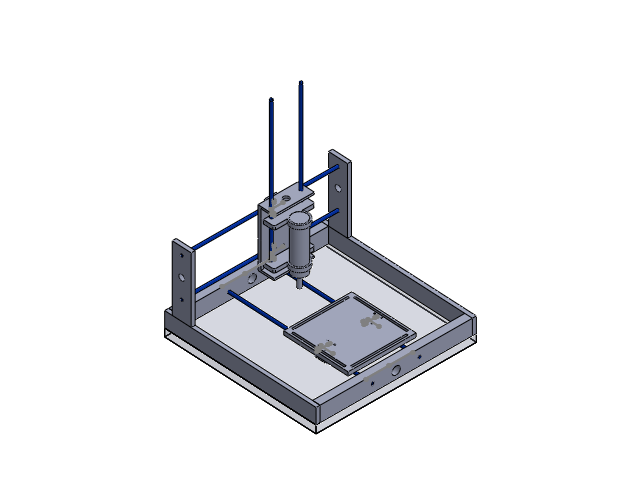
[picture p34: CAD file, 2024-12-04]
3d/Assem5.SLDASM
BASE
FRONTAL_BASE x 2
GUIA_RAIL_VARILLA x 6
GUIA_LINEAL x 4
BASE_PLACA
Part1^Assem2
Part2^Assem2
LADOS x 2
Y
Agarre_motor x 2
spindle

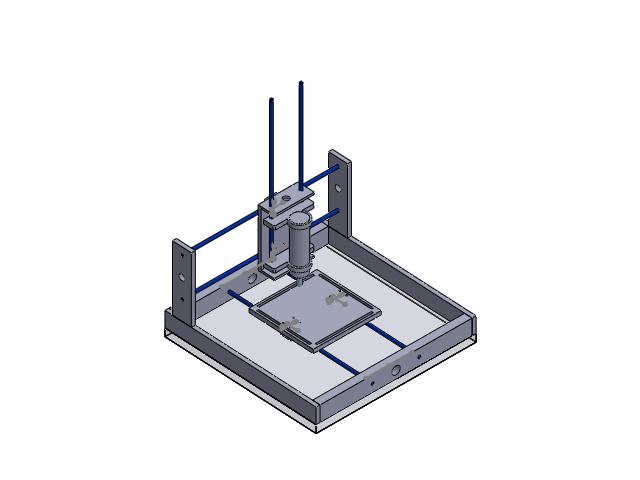
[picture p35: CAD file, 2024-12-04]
3d/Assem7.SLDASM
BASE
FRONTAL_BASE x 2
GUIA_RAIL_VARILLA x 6
GUIA_LINEAL x 4
BASE_PLACA
Part1^Assem7
Part2^Assem7
LADOS x 2
Y
Agarre_motor x 2
spindle

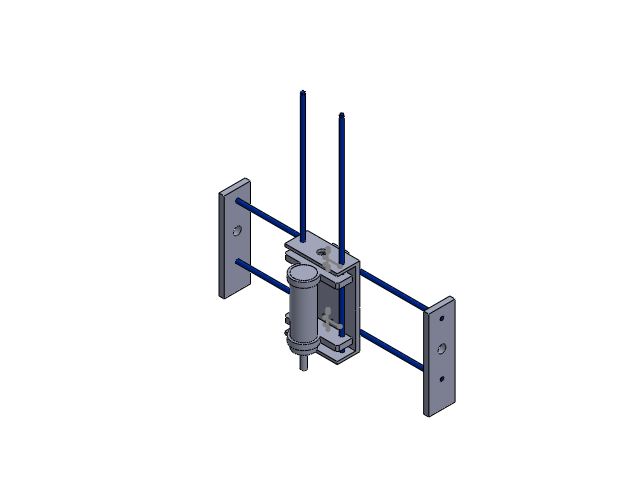
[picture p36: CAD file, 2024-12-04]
3d/XZ.SLDASM
LADOS x 2
GUIA_RAIL_VARILLA x 4
GUIA_LINEAL x 2
Y
Agarre_motor x 2
spindle

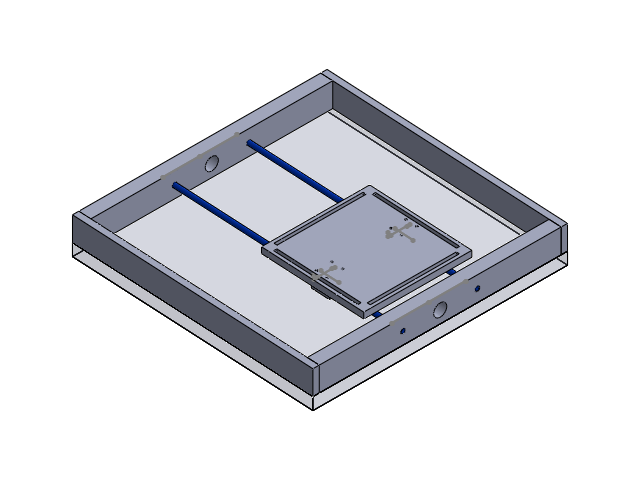
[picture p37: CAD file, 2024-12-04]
3d/Assem2.SLDASM
BASE
FRONTAL_BASE x 2
GUIA_RAIL_VARILLA x 2
GUIA_LINEAL x 2
BASE_PLACA
Part1^Assem2
Part2^Assem2

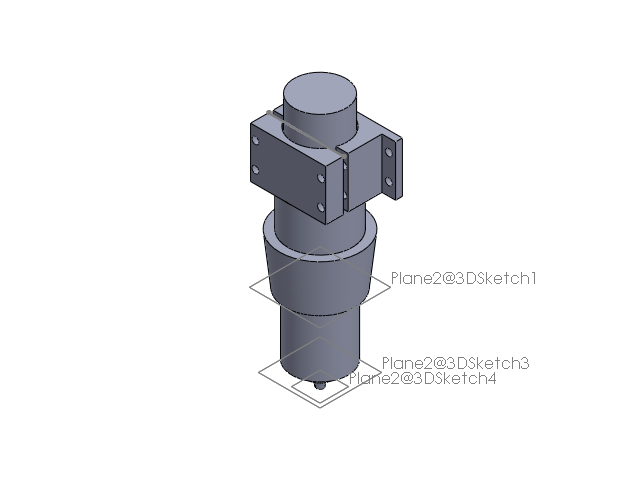
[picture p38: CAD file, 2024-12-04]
3d/v2/Assem3.SLDASM
agarremotor
Motor2

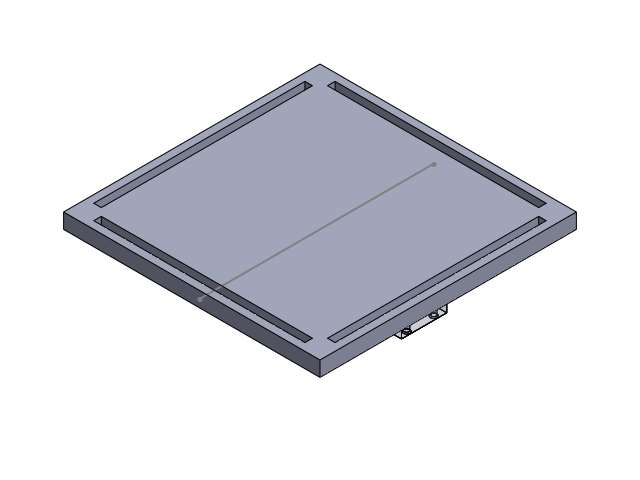
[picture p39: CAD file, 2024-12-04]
3d/Assem4.SLDASM
BASE_PLACA
GUIA_LINEAL x 2

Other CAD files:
3d/Assem10.SLDASM
3d/v2/Assem1.SLDASM
3d/Assem1.SLDASM
3d/BASE_PLACA.SLDPRT
3d/v2/agarreZ.SLDPRT
3d/Agarre_motor.SLDPRT
3d/BASE.SLDPRT
3d/FRONTAL_BASE.SLDPRT
3d/GUIA_LINEAL.SLDPRT
3d/GUIA_RAIL_VARILLA.SLDPRT
3d/Part3.SLDPRT
3d/Part4.SLDPRT
3d/Y.SLDPRT
3d/agarre motor.SLDPRT
3d/paso_a_paso.SLDPRT
3d/sostenmotor.SLDPRT
3d/spindle.SLDPRT
3d/stl/FRONTAL_BASE.STL
3d/stl/Y.STL
3d/v2/BASE2.SLDPRT
3d/v2/GUIA_LINEAL.SLDPRT
3d/v2/GUIA_RAIL_VARILLA.SLDPRT
3d/v2/Motor2.SLDPRT
3d/v2/Motor3.SLDPRT
3d/v2/Part2.SLDPRT
3d/v2/agarre motor.SLDPRT
3d/v2/agarremotor.SLDPRT
3d/v2/paso_a_paso.SLDPRT
3d/v2/soportenema17.SLDPRT
3d/v2/sostenmotor.SLDPRT
3d/v2/varilla_enroscada_Z.SLDPRT
3d/v2/varilla_enroscada_tuerca.SLDPRT
3d/viejo/Agarre_motor.SLDPRT
3d/viejo/Assem1.SLDASM
3d/viejo/Assem10.SLDASM
3d/viejo/BASE_PLACA.SLDPRT
3d/viejo/Part3.SLDPRT
3d/viejo/Part4.SLDPRT
3d/viejo/agarre motor.SLDPRT
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

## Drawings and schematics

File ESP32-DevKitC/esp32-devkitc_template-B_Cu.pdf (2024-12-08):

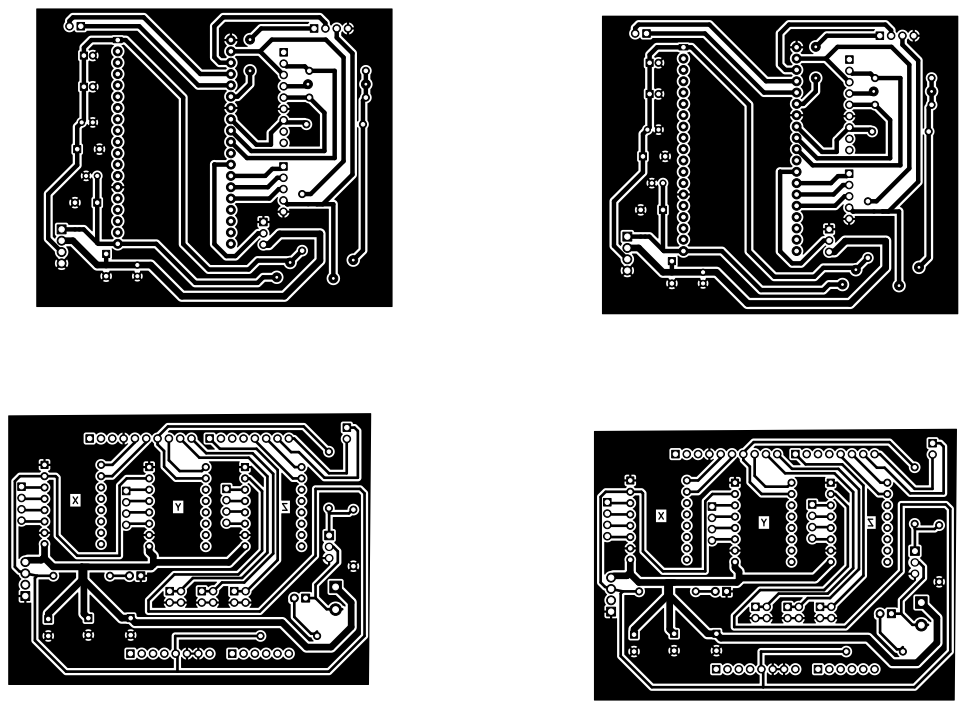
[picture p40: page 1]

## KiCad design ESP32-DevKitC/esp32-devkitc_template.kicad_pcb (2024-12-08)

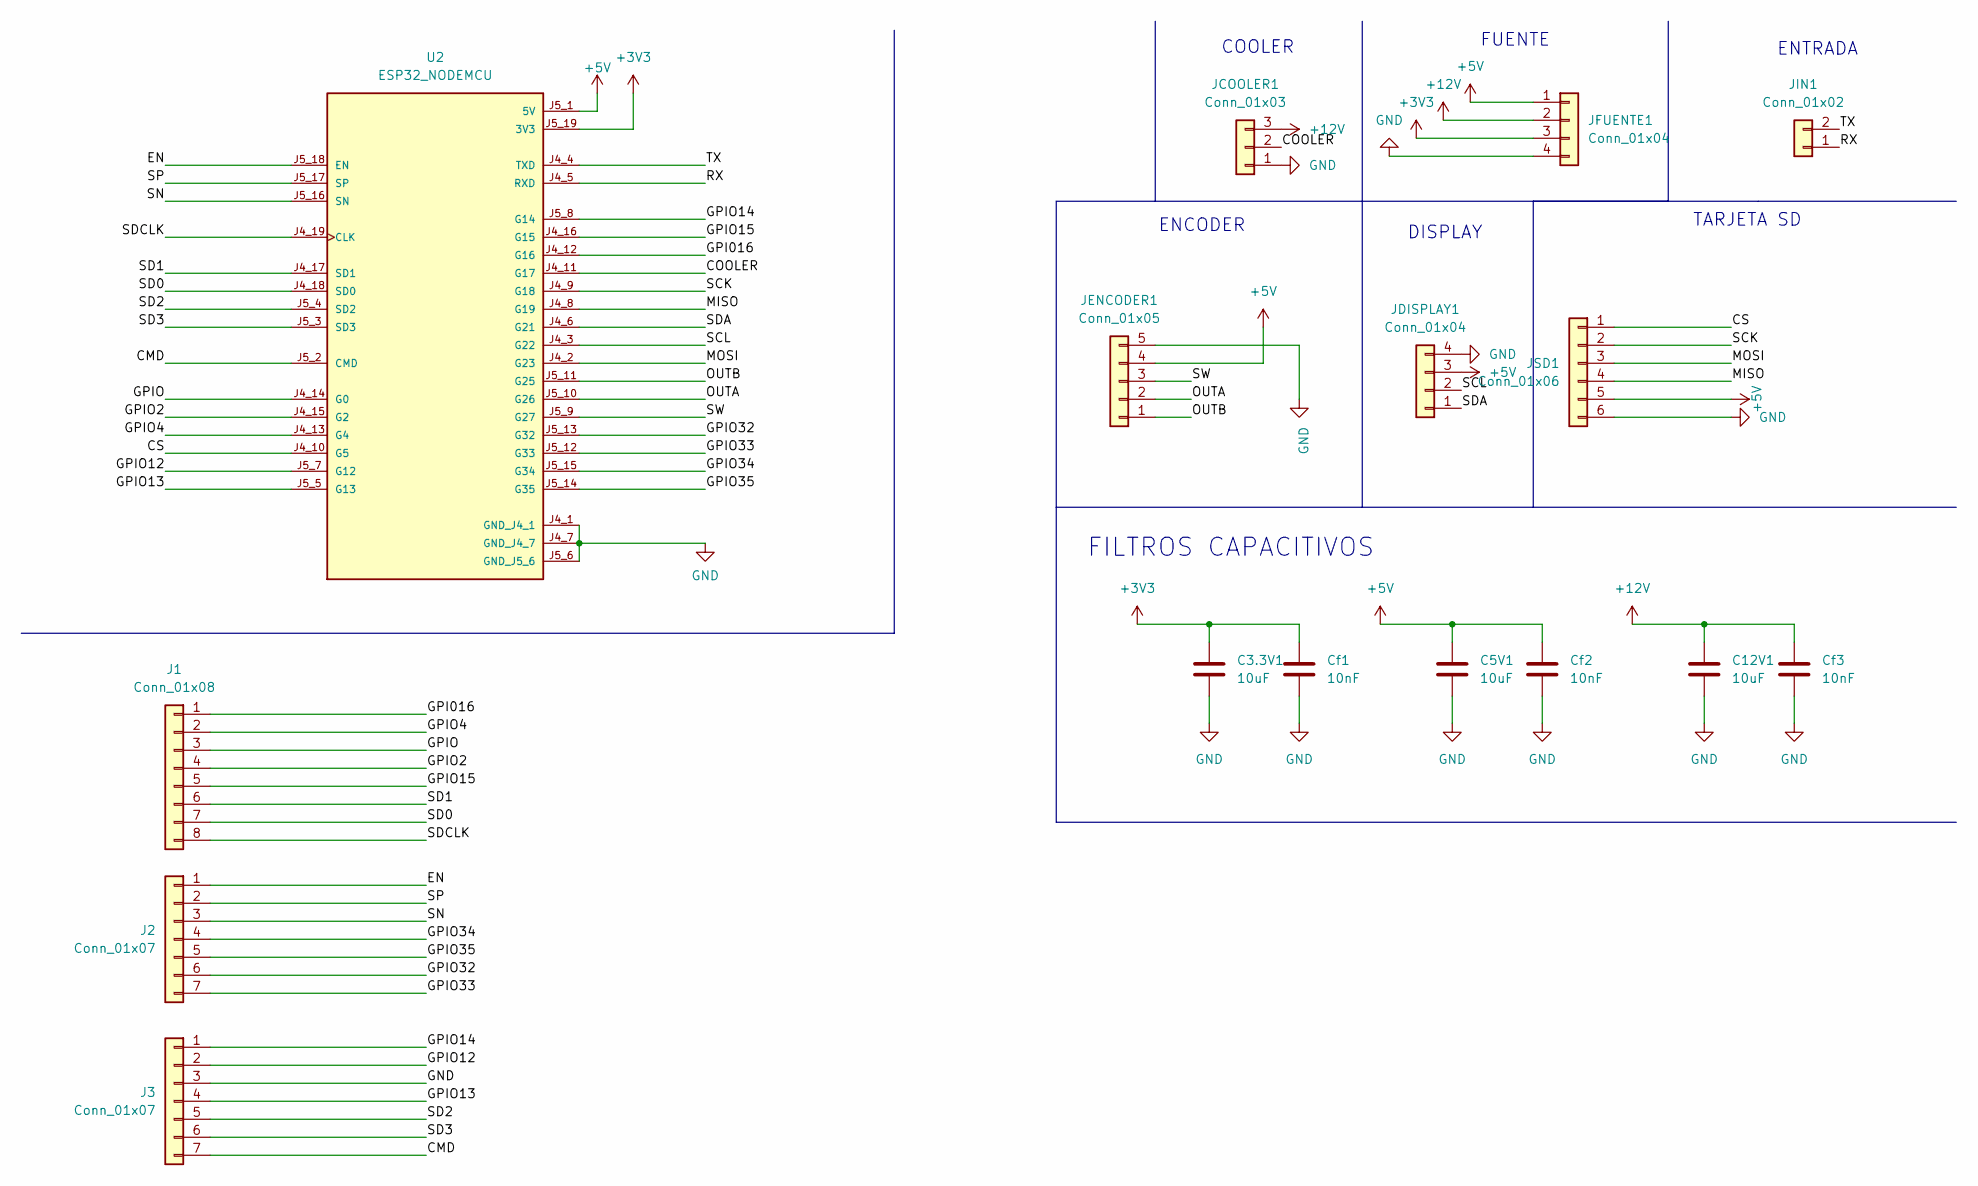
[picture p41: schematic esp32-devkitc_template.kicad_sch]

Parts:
C3.3V1, C5V1, C12V1: 10uF; CP_Radial_D5.0mm_P2.50mm
Cf1, Cf2, Cf3: 10nF; C_Disc_D6.0mm_W2.5mm_P5.00mm
J1: Conn_01x08; PinHeader_1x08_P2.54mm_Vertical
J2, J3: Conn_01x07; PinHeader_1x07_P2.54mm_Vertical
JCOOLER1: Conn_01x03; PinHeader_1x03_P2.54mm_Vertical
JDISPLAY1: Conn_01x04; PinSocket_1x04_P2.54mm_Vertical
JENCODER1: Conn_01x05; PinSocket_1x05_P2.54mm_Vertical
JFUENTE1: Conn_01x04; TerminalBlock_Phoenix_MKDS-1,5-4_1x04_P5.00mm_Horizontal
JIN1: Conn_01x02; PinHeader_1x02_P2.54mm_Vertical
JSD1: Conn_01x06; PinHeader_1x06_P2.54mm_Vertical
U2: ESP32_NODEMCU; MODULE_ESP32_NODEMCU

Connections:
+3V3: C3.3V1.1, Cf1.1, JFUENTE1.3, U2.J5_19 (3V3)
+5V: C5V1.1, Cf2.1, JDISPLAY1.3, JENCODER1.4, JFUENTE1.1, JSD1.5, U2.J5_1 (5V)
+12V: C12V1.1, Cf3.1, JCOOLER1.3, JFUENTE1.2
/CMD: J3.7, U2.J5_2 (CMD)
/COOLER: JCOOLER1.2, U2.J4_11 (G17)
/CS: JSD1.1, U2.J4_10 (G5)
/EN: J2.1, U2.J5_18 (EN)
/GPI016: J1.1, U2.J4_12 (G16)
/GPIO: J1.3, U2.J4_14 (G0)
/GPIO2: J1.4, U2.J4_15 (G2)
/GPIO4: J1.2, U2.J4_13 (G4)
/GPIO12: J3.2, U2.J5_7 (G12)
/GPIO13: J3.4, U2.J5_5 (G13)
/GPIO14: J3.1, U2.J5_8 (G14)
/GPIO15: J1.5, U2.J4_16 (G15)
/GPIO32: J2.6, U2.J5_13 (G32)
/GPIO33: J2.7, U2.J5_12 (G33)
/GPIO34: J2.4, U2.J5_15 (G34)
/GPIO35: J2.5, U2.J5_14 (G35)
/MISO: JSD1.4, U2.J4_8 (G19)
/MOSI: JSD1.3, U2.J4_2 (G23)
/OUTA: JENCODER1.2, U2.J5_10 (G26)
/OUTB: JENCODER1.1, U2.J5_11 (G25)
/RX: JIN1.1, U2.J4_5 (RXD)
/SCK: JSD1.2, U2.J4_9 (G18)
/SCL: JDISPLAY1.2, U2.J4_3 (G22)
/SD0: J1.7, U2.J4_18 (SD0)
/SD1: J1.6, U2.J4_17 (SD1)
/SD2: J3.5, U2.J5_4 (SD2)
/SD3: J3.6, U2.J5_3 (SD3)
/SDA: JDISPLAY1.1, U2.J4_6 (G21)
/SDCLK: J1.8, U2.J4_19 (CLK)
/SN: J2.3, U2.J5_16 (SN)
/SP: J2.2, U2.J5_17 (SP)
/SW: JENCODER1.3, U2.J5_9 (G27)
/TX: JIN1.2, U2.J4_4 (TXD)
GND: C3.3V1.2, C5V1.2, C12V1.2, Cf1.2, Cf2.2, Cf3.2, J3.3, JCOOLER1.1, JDISPLAY1.4, JENCODER1.5, JFUENTE1.4, JSD1.6, U2.J4_1 (GND_J4_1), U2.J4_7 (GND_J4_7), U2.J5_6 (GND_J5_6)

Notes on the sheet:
TARJETA SD
FUENTE
COOLER
FILTROS CAPACITIVOS
ENTRADA
ENCODER
DISPLAY

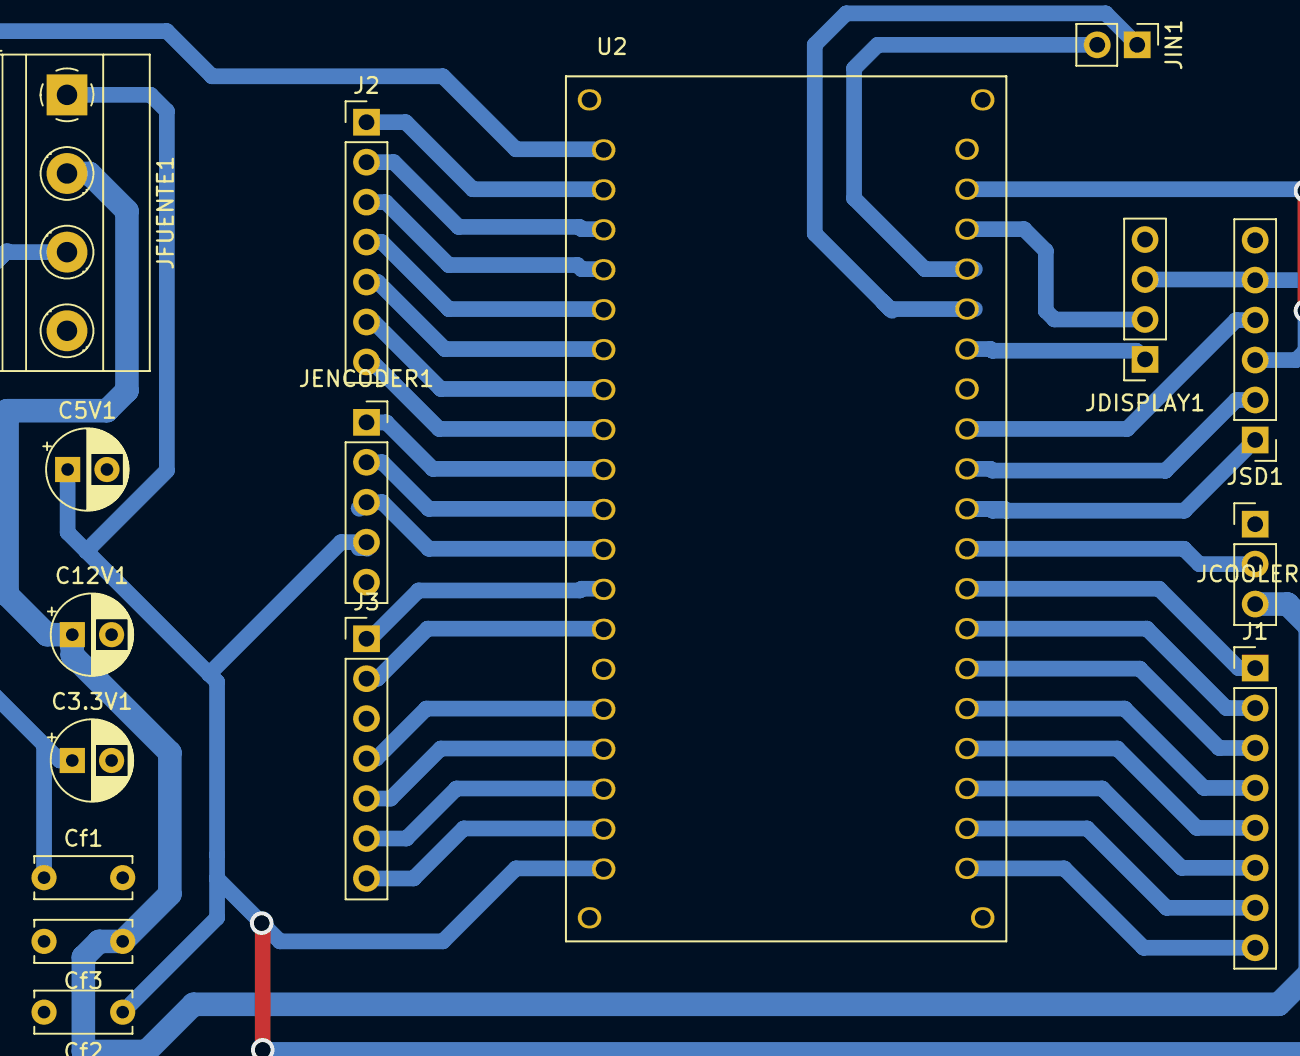
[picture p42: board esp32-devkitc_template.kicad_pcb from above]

Board: 2 copper layers, 16 parts (0 on the bottom side), 37 nets.

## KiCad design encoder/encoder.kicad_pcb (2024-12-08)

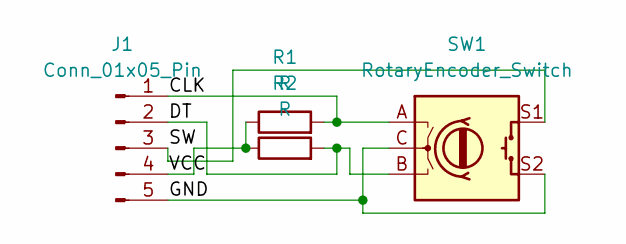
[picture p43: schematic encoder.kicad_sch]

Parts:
J1: Conn_01x05_Pin; PinHeader_1x05_P2.54mm_Vertical
R1, R2: R; R_Axial_DIN0411_L9.9mm_D3.6mm_P12.70mm_Horizontal
SW1: RotaryEncoder_Switch; RotaryEncoder_Alps_EC11E-Switch_Vertical_H20mm

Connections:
/CLK: J1.1, R1.2, SW1.A
/DT: J1.2, R2.2, SW1.B
/GND: J1.5, SW1.C, SW1.S2
/SW: J1.3, SW1.S1
/VCC: J1.4, R1.1, R2.1

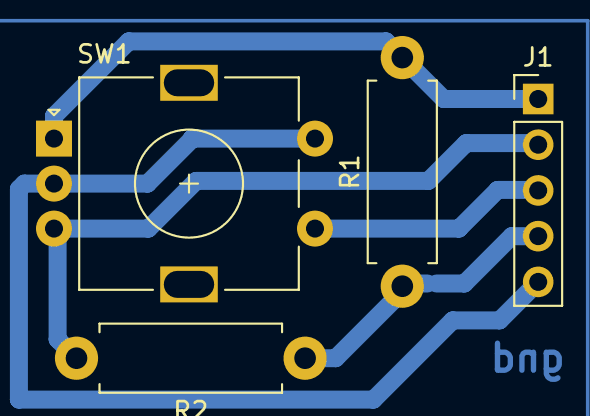
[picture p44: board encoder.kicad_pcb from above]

Board: 2 copper layers, 4 parts (0 on the bottom side), 5 nets.

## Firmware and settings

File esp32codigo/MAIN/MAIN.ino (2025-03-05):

//LCD
#include <Wire.h>

//SD
#include "FS.h"
#include "SD.h"
#include "SPI.h"
#include "globales.h"

void setup() {
  // Inicializar comunicación serial
  COM_SERIAL_SETUP();
  while (!Serial) {
    delay(10);
  }

  // Inicializar tarjeta SD
  sdsetup();
  
  // Inicializar WiFi
  wifisetup();

  // Inicializar LCD
  LCDSetup();
}

void loop() {
  // Actualizar la pantalla LCD
  LCDLoop();
  
  // Actualizar el estado del WiFi
  wifiloop();

  // Manejar la comunicación serial
  COM_SERIAL_LOOP();
}

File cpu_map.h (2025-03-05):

/*
  cpu_map.h - CPU and pin mapping configuration file
  Part of Grbl

  Copyright (c) 2012-2016 Sungeun K. Jeon for Gnea Research LLC

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
  You should have received a copy of the GNU General Public License
  along with Grbl.  If not, see <http://www.gnu.org/licenses/>.
*/

/* The cpu_map.h files serve as a central pin mapping selection file for different
   processor types or alternative pin layouts. This version of Grbl officially supports
   only the Arduino Mega328p. */


#ifndef cpu_map_h
#define cpu_map_h


#ifdef CPU_MAP_ATMEGA328P // (Arduino Uno) Officially supported by Grbl.

  // Define serial port pins and interrupt vectors.
  #define SERIAL_RX     USART_RX_vect
  #define SERIAL_UDRE   USART_UDRE_vect

// Define step pulse output pins. NOTE: All step bit pins must be on the same port.
#define STEP_DDR        DDRD
#define STEP_PORT       PORTD
#define X_STEP_BIT      6  // Uno Digital Pin 2
#define Y_STEP_BIT      4  // Uno Digital Pin 3
#define Z_STEP_BIT      3  // Uno Digital Pin 4
#define STEP_MASK       ((1<<X_STEP_BIT)|(1<<Y_STEP_BIT)|(1<<Z_STEP_BIT)) // All step bits

// Define step direction output pins. NOTE: All direction pins must be on the same port.
#define DIRECTION_DDR     DDRD
#define DIRECTION_PORT    PORTD
#define X_DIRECTION_BIT   7  // Uno Digital Pin 5
#define Y_DIRECTION_BIT   5  // Uno Digital Pin 6
#define Z_DIRECTION_BIT   2  // Uno Digital Pin 7
#define DIRECTION_MASK    ((1<<X_DIRECTION_BIT)|(1<<Y_DIRECTION_BIT)|(1<<Z_DIRECTION_BIT)) // All direction bits

  // Define stepper driver enable/disable output pin.
  #define STEPPERS_DISABLE_DDR    DDRB
  #define STEPPERS_DISABLE_PORT   PORTB
  #define STEPPERS_DISABLE_BIT    0  // Uno Digital Pin 8
  #define STEPPERS_DISABLE_MASK   (1<<STEPPERS_DISABLE_BIT)

  // Define homing/hard limit switch input pins and limit interrupt vectors.
  // NOTE: All limit bit pins must be on the same port, but not on a port with other input pins (CONTROL).
  #define LIMIT_DDR        DDRB
  #define LIMIT_PIN        PINB
  #define LIMIT_PORT       PORTB
  #define X_LIMIT_BIT      1  // Uno Digital Pin 9
  #define Y_LIMIT_BIT      2  // Uno Digital Pin 10
  #ifdef VARIABLE_SPINDLE // Z Limit pin and spindle enabled swapped to access hardware PWM on Pin 11.
    #define Z_LIMIT_BIT	   4 // Uno Digital Pin 12
  #else
    #define Z_LIMIT_BIT    4  // Uno Digital Pin 11
  #endif
  #if !defined(ENABLE_DUAL_AXIS)
    #define LIMIT_MASK     ((1<<X_LIMIT_BIT)|(1<<Y_LIMIT_BIT)|(1<<Z_LIMIT_BIT)) // All limit bits
  #endif
  #define LIMIT_INT        PCIE0  // Pin change interrupt enable pin
  #define LIMIT_INT_vect   PCINT0_vect
  #define LIMIT_PCMSK      PCMSK0 // Pin change interrupt register

  // Define user-control controls (cycle start, reset, feed hold) input pins.
  // NOTE: All CONTROLs pins must be on the same port and not on a port with other input pins (limits).
  #define CONTROL_DDR       DDRC
  #define CONTROL_PIN       PINC
  #define CONTROL_PORT      PORTC
  #define CONTROL_RESET_BIT         0  // Uno Analog Pin 0
  #define CONTROL_FEED_HOLD_BIT     1  // Uno Analog Pin 1
  #define CONTROL_CYCLE_START_BIT   2  // Uno Analog Pin 2
  #define CONTROL_SAFETY_DOOR_BIT   1  // Uno Analog Pin 1 NOTE: Safety door is shared with feed hold. Enabled by config define.
  #define CONTROL_INT       PCIE1  // Pin change interrupt enable pin
  #define CONTROL_INT_vect  PCINT1_vect
  #define CONTROL_PCMSK     PCMSK1 // Pin change interrupt register
  #define CONTROL_MASK      ((1<<CONTROL_RESET_BIT)|(1<<CONTROL_FEED_HOLD_BIT)|(1<<CONTROL_CYCLE_START_BIT)|(1<<CONTROL_SAFETY_DOOR_BIT))
  #define CONTROL_INVERT_MASK   CONTROL_MASK // May be re-defined to only invert certain control pins.

  // Define probe switch input pin.
  #define PROBE_DDR       DDRC
  #define PROBE_PIN       PINC
  #define PROBE_PORT      PORTC
  #define PROBE_BIT       5  // Uno Analog Pin 5
  #define PROBE_MASK      (1<<PROBE_BIT)

  #if !defined(ENABLE_DUAL_AXIS)

    // Define flood and mist coolant enable output pins.
    #define COOLANT_FLOOD_DDR   DDRC
    #define COOLANT_FLOOD_PORT  PORTC
    #define COOLANT_FLOOD_BIT   3  // Uno Analog Pin 3
    #define COOLANT_MIST_DDR   DDRC
    #define COOLANT_MIST_PORT  PORTC
    #define COOLANT_MIST_BIT   4  // Uno Analog Pin 4

    // Define spindle enable and spindle direction output pins.
    #define SPINDLE_ENABLE_DDR    DDRB
    #define SPINDLE_ENABLE_PORT   PORTB
    // Z Limit pin and spindle PWM/enable pin swapped to access hardware PWM on Pin 11.
    #ifdef VARIABLE_SPINDLE
      #ifdef USE_SPINDLE_DIR_AS_ENABLE_PIN
        // If enabled, spindle direction pin now used as spindle enable, while PWM remains on D11.
        #define SPINDLE_ENABLE_BIT    3  // Uno Digital Pin 13 (NOTE: D13 can't be pulled-high input due to LED.)
      #else
        #define SPINDLE_ENABLE_BIT    3  // Uno Digital Pin 11
      #endif
    #else
      #define SPINDLE_ENABLE_BIT    3  // Uno Digital Pin 12
    #endif
    #ifndef USE_SPINDLE_DIR_AS_ENABLE_PIN
      #define SPINDLE_DIRECTION_DDR   DDRB
      #define SPINDLE_DIRECTION_PORT  PORTB
      #define SPINDLE_DIRECTION_BIT   3  // Uno Digital Pin 13 (NOTE: D13 can't be pulled-high input due to LED.)
    #endif

    // Variable spindle configuration below. Do not change unless you know what you are doing.
    // NOTE: Only used when variable spindle is enabled.
    #define SPINDLE_PWM_MAX_VALUE     255 // Don't change. 328p fast PWM mode fixes top value as 255.
    #ifndef SPINDLE_PWM_MIN_VALUE
      #define SPINDLE_PWM_MIN_VALUE   1   // Must be greater than zero.
    #endif
    #define SPINDLE_PWM_OFF_VALUE     0
    #define SPINDLE_PWM_RANGE         (SPINDLE_PWM_MAX_VALUE-SPINDLE_PWM_MIN_VALUE)
    #define SPINDLE_TCCRA_REGISTER    TCCR2A
    #define SPINDLE_TCCRB_REGISTER    TCCR2B
    #define SPINDLE_OCR_REGISTER      OCR2A
    #define SPINDLE_COMB_BIT          COM2A1

    // Prescaled, 8-bit Fast PWM mode.
    #define SPINDLE_TCCRA_INIT_MASK   ((1<<WGM20) | (1<<WGM21))  // Configures fast PWM mode.
    // #define SPINDLE_TCCRB_INIT_MASK   (1<<CS20)               // Disable prescaler -> 62.5kHz
    // #define SPINDLE_TCCRB_INIT_MASK   (1<<CS21)               // 1/8 prescaler -> 7.8kHz (Used in v0.9)
    // #define SPINDLE_TCCRB_INIT_MASK   ((1<<CS21) | (1<<CS20)) // 1/32 prescaler -> 1.96kHz
    #define SPINDLE_TCCRB_INIT_MASK      (1<<CS22)               // 1/64 prescaler -> 0.98kHz (J-tech laser)

    // NOTE: On the 328p, these must be the same as the SPINDLE_ENABLE settings.
    #define SPINDLE_PWM_DDR   DDRB
    #define SPINDLE_PWM_PORT  PORTB
    #define SPINDLE_PWM_BIT   3    // Uno Digital Pin 11
  
  #else

    // Dual axis feature requires an independent step pulse pin to operate. The independent direction pin is not 
    // absolutely necessary but facilitates easy direction inverting with a Grbl $$ setting. These pins replace 
    // the spindle direction and optional coolant mist pins.
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

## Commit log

2024-12-08 3d terminado
    [Assem2.SLDASM, BASE_PLACA.SLDPRT, FRONTAL_BASE.SLDPRT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]
2024-12-17 placa motores
    [ARD-MOTORES2.kicad_pcb, ARD-MOTORES2.kicad_sch, placa motores.kicad_pcb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]

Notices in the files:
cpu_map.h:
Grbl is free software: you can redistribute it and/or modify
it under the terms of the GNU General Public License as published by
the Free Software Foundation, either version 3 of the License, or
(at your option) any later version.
